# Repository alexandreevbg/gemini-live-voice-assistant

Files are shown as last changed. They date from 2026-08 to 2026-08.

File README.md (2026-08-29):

# Chochko: Multilingual Gemini Voice Assistant

A high-performance, private voice assistant, featuring multilingual wake word detection and Google Gemini Live integration.

## Project Overview
Project highlights:
- **Hardware:** Raspberry Pi + ReSpeaker 2-Mic v2.0
- **Platform:** Raspberry Pi OS Trixie (Debian 13) · Python 3.13 · aarch64
- **Advanced Audio Processing:** Utilizes PipeWire with Acoustic Echo Cancellation (AEC) for voice capture
- **On-Device Wake Word Detection:** Efficient and private wake word recognition based on MicroWakeWord models
- **Gemini Live Integration:** Seamless conversational AI powered by Google's **Gemini Live API**

Optional features:
- **Custom Wake Word:** Training a custom MicroWakeWord model, provided Bulgarian **"Чочко"** as an example
- **Home Assistant:** Optional integration for smart device control
- **Spotify:** for music streaming from Spotify or Home Assistant Media Player

More technical details:
- **Linux Kernel:** 6.18.39+rpt-rpi-v8 · aarch64
- **Python version:** 3.13.5
- **pymicro-wakeword:** bundles its own TFLite C library — no ai-edge-litert/tflite-runtime needed

## Repository structure
Besides a specific instruction file in each folder, you can find the related resources in:
- **01-platform** - Makefile to compile and setup ReSpeaker drivers and ReSpeaker schematic diagram
- **02-tools** - Python scripts for headless WiFi captive portal
- **03-environment** - Template for definition of environment variables and music clip for test AEC
- **04-wakeword** - Install/test MicroWakeWord, obtain or train a wake word model (pretrained, Colab, or local)
- **05-voice_assist** - The voice assistant package in Python
- **06-enclosure** - 3D printing files (STL), exploded component view, and hardware wiring diagrams

## Implementation Roadmap

Follow these steps to build your voice assistant:

----
### 1. [Platform Setup](./01-platform/platform.md)
Hardware specifications, flashing Raspberry Pi OS (Trixie), and compiling ReSpeaker 2-mic v2.0 drivers.

### 2. [Python and Tools](./02-tools/tools.md)
Create a common Python environment, and install the system backup tool, headless Wi-Fi captive portal, and Raspotify integration.

### 3. [Environment & Audio Stack](./03-environment/environment.md)
Install, setup, and test PipeWire with AEC (Acoustic Echo Cancellation).

### 4. [Wake Word & Training](./04-wakeword/wakeword.md)
Install and test the microWakeWord library. Obtain a keyword model, or create one via a pretrained model, Colab notebook (English), or local training (any language supported by Google and/or Edge TTS).

### 5. [Voice Assistant Core](./05-voice_assist/voice_assist.md)
Install, setup and test the main Python package, Gemini API integration, and optional Home Assistant and Spotify integrations.

### 6. [Enclosure & Assembly](./06-enclosure/enclosure.md)
An enclosure for the voice assistant in the form of 3D printing files (STL), exploded component view, and a wiring diagram.

---
---
---
## 📜 License
This project is licensed under the MIT License - see the [LICENSE](https://opensource.org/license/mit) file for details.

---

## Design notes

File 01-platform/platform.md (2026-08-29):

# Platform: Hardware, OS, and Drivers

This guide covers the base layer of the assistant, including hardware specifications, OS installation, and driver setup for the ReSpeaker 2-mic HAT v2.0.

----

## Hardware Requirements
| Component | Specification |
|---|---|
| **SBC** | Raspberry Pi Zero 2W |
| **Audio** | Seeed Studio ReSpeaker 2-Mic HAT v2.0 |
| **SD Card** | 16GB+ Class 10 |

## 1. Install Raspberry Pi OS (64-bit) Lite

Use **Raspberry Pi Imager** to flash your SD card:
- **Device:** Raspberry Pi Zero 2W
- **OS:** Raspberry Pi OS Lite (64-bit). This project is tested on **Debian 13 (Trixie)** / Testing branch for Python 3.13 support.
- **Settings:** Enable SSH, set your username (e.g., `chochko`), and configure your Wi-Fi credentials.

### Preliminary System Configuration
Optimize the system for headless use and speed up SSH login:

   ```bash
   # Enable passwordless sudo for the current user
   echo "$USER ALL=(ALL) NOPASSWD: ALL" | sudo tee /etc/sudoers.d/010_nopasswd

   # If login takes too much time, then disable motd scripts
   sudo chmod -x /etc/update-motd.d/*
   ```

Disable onboard audio and Bluetooth to prevent conflicts and save resources:
   ```bash
   sudo nano /boot/firmware/config.txt
   ```
   Change the following lines:
   ```bash
   dtparam=audio=off
   dtoverlay=vc4-kms-v3d,noaudio # Ensure this line is present and uncommented
   ```
   And add the following line to the end of the file:
   ```bash
   dtoverlay=disable-bt             # disable bluetooth if not used
   ```

Monitor CPU Temperature
   ```bash
   watch 'vcgencmd measure_temp'
  ```   

## 2. Install Drivers for ReSpeaker 2-mic HAT

Since newer kernels require manual building of the TLV320AIC3104 codec driver:

#### Build the Driver
   ```bash
   ## Install kernel
   sudo apt update
   sudo apt install flex bison libssl-dev bc build-essential libncurses-dev git device-tree-compiler -y
   git clone --depth=1 --branch rpi-6.12.y https://github.com/raspberrypi/linux.git

   ## Copy code and a Makefile
   mkdir ~/tlv320aic3x_i2c_driver
   cd ~/tlv320aic3x_i2c_driver
   cp ~/linux/sound/soc/codecs/tlv320aic3x.c .
   cp ~/linux/sound/soc/codecs/tlv320aic3x.h .
   cp ~/linux/sound/soc/codecs/tlv320aic3x-i2c.c .

   # Use the Makefile provided in the 01-platform directory of this repo
   wget https://raw.githubusercontent.com/alexandreevbg/gemini-live-voice-assistant/main/01-platform/Makefile

   ## Build the driver 
   make
   sudo make install
   sudo modprobe snd-soc-tlv320aic3x-i2c
   ```

#### Install the Overlay
   ```bash
   curl -L https://raw.githubusercontent.com/Seeed-Studio/seeed-linux-dtoverlays/master/overlays/rpi/respeaker-2mic-v2_0-overlay.dts -o respeaker-2mic-v2_0-overlay.dts
   dtc -I dts respeaker-2mic-v2_0-overlay.dts -o respeaker-2mic-v2_0-overlay.dtbo
   sudo cp respeaker-2mic-v2_0-overlay.dtbo /boot/firmware/overlays/
   ```

Add the overlay to `config.txt`:
   ```bash
echo "dtoverlay=respeaker-2mic-v2_0-overlay" | sudo tee -a /boot/firmware/config.txt
sudo reboot
   ```

## 3. Audio Testing & ALSA Calibration

Check if the card is detected:
   ```bash
   aplay -l
   arecord -l
   ```
It should appear as `card 0: seeed2micvoicec`.

### Set Gains via Alsamixer
   Run `alsamixer` and configure the following important sliders:
   - **PCM**: Master output volume - set to 100%
   - **Line DAC**: Max output voulme limit - set to 66
   - **PGA / Capture**: microphone Analog Gain - set to ~34%
   - **AGC**: Automatic Gain Control - recommended to turn it **OFF**

Save levels with:
   ```bash
   sudo alsactl store
   ```   

Test recording:
   ```bash
   arecord -r 16000 -c 1 -f S16_LE -t wav -d 5 test.wav
   aplay test.wav
   ```

Cleanup source fles:
   ```bash
   cd ~ 
   rm -rf ~/linux
   ```

---
[Return to Main README](../README.md)

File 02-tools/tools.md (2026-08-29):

# Tools: Python Environment, WiFi Captive Portal, Backup, Raspotify

This part guides through the setup of the Python virtual environment and installation of three optional, but recommended tools:
1. System backup tool - a fast and efficient backup tool for IoT project
2. Headless Wi-Fi captive portal - if you plan to travel with your device
3. Raspotify - Spotify Connect client for Raspberry Pi - if you plan to play music on your device  

You can install the optional tools later.

---

## 1. Python Virtual Environment
We use a shared virtual environment (`~/.venv`) to manage Python dependencies efficiently and consistently across different project components.

```bash
sudo apt update
sudo apt install -y python3-venv python3-pip
python3 -m venv --system-site-packages ~/.venv
```

Download the project locally
```bash
cd ~
git clone https://github.com/alexandreevbg/gemini-live-voice-assistant.git
```

## 2. Install the optional tools

### 1. System backup tool
For a backup solution, use **RonR-RPi-image-utils**, which quickly and efficiently creates a complete backup of a Raspberry Pi in the form of an image file.

Install NFS and the backup application
   ```bash
   sudo apt update
   sudo apt install nfs-common git -y
   git clone https://github.com/seamusdemora/RonR-RPi-image-utils
   sudo install --mode=755 ./RonR-RPi-image-utils/image-* /usr/local/sbin
   ```
Mount an external drive to store the image and run backup
   ```bash
   sudo mount -t nfs -o proto=tcp,port=2049 <NAS IP address>/<target directory> /mnt
   sudo image-backup -o -v
   ```
   After running the command, enter the name of the target image to /mnt/image_name.img, then answer with [OK] and 'y' to the subsequent questions. The resulting image is typically less than or about 4 GB. You may compress it using 7-Zip to a *.img.xz file with a size of less than 1 GB. Then, you can flash the image by Raspberry Pi Imager from the resulting or compressed image. 

---

### 2. Headless Wi-Fi captive portal
#### Reading the lights
| Light | What it means | What to do |
|---|---|---|
| 💙 **Blue flash** (once) | Starting up | Nothing — just booting |
| ❤️ **Red blinking** | Can't reach the internet | Wait, or press the button to set up Wi-Fi |
| 💙 **Blue pulsing** | Setup mode is on | Connect your phone (see below) |
| ⚫ **Off** | Connected and working | Nothing — you're good |

After power-on, the device flashes blue once, then tries to connect to a previously used Wi-Fi network. If it gets online, the light stays off and the device is ready. 
If it can't connect, the device blinks red 10 times, then tries again. This cycle repeats until a connection is established — or until you press the button to open the captive portal.
- **SSID**: Chochko-WiFi-Setup
- **Password**: chochko123
- **Portal address**: 192.168.4.1

Connect with your phone or computer, select a network from the list, enter the password, and press Connect. The device tries to connect and then reboots (whether or not it succeeded — if it failed, you'll see red blinking again and can retry).

If you don't finish within 300 seconds, the portal closes and the device returns to red blinking. Press the button to reopen the portal, or disconnect the power to reboot.

You can also open the captive portal at any time by pressing and holding the button during boot until the light starts pulsing blue.

1. Install the LED driver library into the shared environment:
   ```bash
   ~/.venv/bin/pip install --upgrade pip setuptools
   ~/.venv/bin/pip install apa102-pi
   ```
2. Enable SPI interface in the Raspberry Pi configuration:
   ```bash
   sudo raspi-config
   ```
   Select "Interfacing Options" -> "SPI" -> "Yes".
3. Get the source scripts
   ```bash
   mv gemini-live-voice-assistant/02-tools/wifi-portal ~/wifi-config
   ```
4. Test the Wi-Fi configuration manually
   ```bash
   sudo ~/.venv/bin/python ~/wifi-config/wifi_portal.py
   ```
   When run, the device should blink once with blue light
5. Create a one-shot service for the portal
   ```bash
   sudo nano /etc/systemd/system/wifi-config.service
   ```
   Add the following content to the file. This service runs as `root` after the network comes online, executing the portal script from the correct directory and using the Python virtual environment.
   > **Note**: Replace `chochko` with your actual username if it's different.
   ```ini
   [Unit]
   Description=Wi-Fi Configuration Portal
   Wants=network-online.target
   After=network-online.target

   [Service]
   Type=oneshot
   User=root
   WorkingDirectory=/home/chochko/wifi-config
   ExecStart=/home/chochko/.venv/bin/python /home/chochko/wifi-config/wifi_portal.py

   [Install]
   WantedBy=multi-user.target
   ```
   Then, enable the service to run on boot:
   ```bash
   sudo systemctl enable wifi-config.service
   sudo reboot
   ```
You can change the captive portal parameters as SSID name/password and/or the portal address in the file `wifi-config/wifi_portal.py`.   

---

### 3. Raspotify - Spotify Connect client
To integrate with Spotify, we need to install **raspotify**. It creates a network player compatible with Spotify and Home Assistant.

1. install raspotify:

   ```bash
   sudo apt update
   curl -sL https://dtcooper.github.io/raspotify/install.sh | sh
   sudo systemctl status raspotify
   ```

2. Test the installation:
Run Spotify on your phone connected to the same WiFi SSID. Play some music, open devices menu, and select raspotify(chochko).

> **If you plan to also install PipeWire+AEC** (`03-environment.md`), raspotify's packaged system service will stop working once PipeWire takes ownership of the audio hardware (`snd_pcm_open ... Host is down`) — this happens regardless of which you install first. See `03-environment.md`'s "Raspotify vs PipeWire" section for the one-time fix (swapping to a user-level service). If you're not using PipeWire/AEC, no further action is needed here.

---
[Return to Main README](../README.md)

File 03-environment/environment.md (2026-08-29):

# Environment & Audio Stack
This section details the setup of the PipeWire audio server with Acoustic Echo Cancellation (AEC), an output limiter/compressor that keeps playback clean for the echo canceller, and essential configuration files.

## 1. Install PipeWire + AEC
PipeWire is used to manage audio streams and enable Acoustic Echo Cancellation (AEC), allowing the microphone to effectively filter out audio being played by the speaker.

Install PipeWire and its related components.
```bash
sudo apt install -y \
    pipewire \
    pipewire-alsa \
    pipewire-audio \
    wireplumber \
    libspa-0.2-modules
```    
Validate installation
```bash
pipewire --version
```
The expected version is 1.4.2 or newer.

## 2. Set AEC config
Create the necessary configuration directories and files for PipeWire and WirePlumber.
```bash
mkdir -p ~/.config/pipewire/pipewire.conf.d ~/.config/wireplumber/wireplumber.conf.d
```

Set Clock Configuration
```bash
nano ~/.config/pipewire/pipewire.conf.d/10-clock.conf
```
Copy/paste the following text into the file:
```text
context.properties = {
    default.clock.rate = 48000
    default.clock.allowed-rates = [ 48000 ]
    default.clock.quantum = 480
    default.clock.min-quantum = 480
    default.clock.max-quantum = 480
}
```

Set Echo Cancellation Configuration
```bash
nano ~/.config/pipewire/pipewire.conf.d/90-echo-cancel.conf
```
Copy/paste the following text into the file:
```text
context.modules = [
  {
    name = libpipewire-module-echo-cancel
    args = {
      library.name = "aec/libspa-aec-webrtc"

      # The AEC engine now runs in MONO
      audio.rate = 48000
      audio.channels = 1
      audio.position = [ MONO ]

      webrtc.high_pass_filter = true
      webrtc.noise_suppression = true       # rejects ambient room noise (helps the wake-word detector)
      webrtc.voice_detection = false
      # AGC off: it pumped the gain and dropped quiet syllables. Keep capture level fixed instead.
      webrtc.gain_control = false
      webrtc.experimental_agc = false
      webrtc.limiter = true
      webrtc.extended_filter = true         # models the longer echo tail
      # delay_agnostic off: speaker+mic share a fixed-latency board, so constant delay
      # re-estimation only caused spectral "wobble". A fixed path converges far cleaner.
      webrtc.delay_agnostic = false
      webrtc.experimental_ns = false        # second NS stage gated quiet speech
      webrtc.transient_suppression = false  # was clipping word onsets

      capture.props = {
        node.name = "aec_capture"
        # This MUST match the real ALSA node name from `wpctl status` / `pw-link -lo`.
        # On this hardware the active profile names it "stereo-fallback" (not "analog-stereo").
        target.object = "alsa_input.platform-soc_sound.stereo-fallback"
        
        # Hardware stays Stereo to keep driver happy
        audio.channels = 2
        audio.position = [ FL FR ]
        node.force-rate = 48000
        node.force-quantum = 480
      }
      source.props = {
        node.name = "aec_input"
        node.description = "Echo-Cancelled Mono Mic"
        media.class = "Audio/Source"
        audio.channels = 1
        audio.position = [ MONO ]
        priority.driver = 1500
        priority.session = 1500      
	  }
      sink.props = {
        node.name = "aec_output"
        node.description = "Echo-Cancel Mono Reference"
        media.class = "Audio/Sink"
        audio.channels = 1
        audio.position = [ MONO ]
        priority.driver = 1500
        priority.session = 1500      
	  }
      playback.props = {
        node.name = "aec_playback"
        # MUST match the real ALSA node name (see note in capture.props above).
        target.object = "alsa_output.platform-soc_sound.stereo-fallback"
        # Playback remains Mono (PipeWire will mix it to the single speaker)
        audio.channels = 1
        audio.position = [ MONO ]
        node.force-rate = 48000
        node.force-quantum = 480
      }
    }
  }
]
```

Force Quantum Rate for ALSA
```bash
nano ~/.config/wireplumber/wireplumber.conf.d/50-force-480.conf
```
Copy/paste the following text into the file:
```text
monitor.alsa.rules = [
  {
    matches = [ { node.name = "~alsa_input.*" } ]
    actions = { update-props = { node.force-quantum = 480 } }
  },
  {
    matches = [ { node.name = "~alsa_output.*" } ]
    actions = { update-props = { node.force-quantum = 480 } }
  }
]
```

## 3. Output Limiter / Compressor
The WebRTC `limiter` enabled above only acts on the **capture** (microphone) signal — it does **not** touch the audio sent to the speaker. The ReSpeaker amplifier outputs ~1 W into a 3 W speaker, so the speaker itself is never at risk. The real problem is **distortion**: because section 7 forces the PCM slider to 100%, a loud TTS response or music spike can clip the amplifier. When that happens, the acoustic output is no longer a linear copy of the playback signal — and the WebRTC echo canceller assumes the echo *is* a linear function of its reference. Clipping breaks that assumption, so cancellation degrades and echo leaks into the mic. An independent `filter-chain` limiter/compressor on the **output** path keeps the signal below the clipping point, so the amp stays linear and AEC can do its job (it also evens out loudness so the assistant's voice stays consistent).

It is placed **before** the AEC sink (`apps → limiter_sink → aec_output → AEC → speaker`) so the echo reference is exactly the (already-limited) signal that reaches the speaker — preserving the linear relationship AEC depends on, since nothing after this point adds gain.

Install the LADSPA plugin set (provides the mono SC4 compressor/limiter):
```bash
sudo apt install -y swh-plugins
```
Confirm the plugin file is present (the control-port names used below are the standard swh-plugins names):
```bash
ls -l /usr/lib/ladspa/sc4m_1916.so
```
> **Note**: On 64-bit systems the plugin may instead live under an arch-specific path. If the command above fails, check `/usr/lib/aarch64-linux-gnu/ladspa/` and set `LADSPA_PATH` accordingly so PipeWire can find it.

```bash
nano ~/.config/pipewire/pipewire.conf.d/95-limiter.conf
```
Copy/paste the following text into the file:
```text
context.modules = [
  {
    name = libpipewire-module-filter-chain
    args = {
      node.description = "Speaker Limiter"
      media.name       = "Speaker Limiter"

      filter.graph = {
        nodes = [
          {
            type   = ladspa
            name   = comp
            plugin = sc4m_1916
            label  = sc4m
            control = {
              # 0 = RMS (smoother), 1 = peak (faster/harder)
              "RMS/peak"          = 0.0
              "Attack time (ms)"  = 10.0
              "Release time (ms)" = 150.0
              # Lower threshold + higher ratio = more limiting.
              "Threshold level (dB)" = -12.0
              "Ratio (1:n)"          = 6.0
              "Knee radius (dB)"     = 3.0
              # Keep makeup low so peaks stay below clipping; raise it for louder output.
              "Makeup gain (dB)"     = 2.0
            }
          }
        ]
      }

      # Virtual sink that apps play into (make this your default output)
      capture.props = {
        node.name        = "limiter_sink"
        node.description = "Limiter Output (Clean Playback for AEC)"
        media.class      = "Audio/Sink"
        audio.channels   = 1
        audio.position   = [ MONO ]
      }
      # Forward the limited signal into the AEC sink
      playback.props = {
        node.name      = "limiter_playback"
        target.object  = "aec_output"
        audio.channels = 1
        audio.position = [ MONO ]
      }
    }
  }
]
```
**Tuning:** For hard **clip protection** (brick-wall behaviour, keeps the amp out of distortion) set `"Ratio (1:n)" = 20.0`, `"Threshold level (dB)" = -6.0`, and `"Makeup gain (dB)" = 0.0`. For **loudness consistency** (voice assistant), use a lower ratio (3–6) with a few dB of makeup gain as above.

 Reboot
```bash
sudo reboot
```

**⚠ Verify the routing after restart.** With both this filter and the AEC active, the graph must form the chain `limiter_sink → aec_output → aec_playback → hardware`. Confirm the links — *not* just that nodes exist:
```bash
pw-link -lo
```
You must see exactly these connections:
```text
limiter_playback:output_MONO   ->   # limiter feeds the AEC reference
  |->aec_output:playback_MONO                    
aec_playback:output_FL              # AEC feeds the speaker
  |-> alsa_output.platform-soc_sound.stereo-fallback:playback_FL
aec_playback:output_FR
  |-> alsa_output.platform-soc_sound.stereo-fallback:playback_FR
```
If instead `aec_playback` connects to `limiter_sink`, or `limiter_playback` connects to the hardware, the chain is inverted — the AEC reference is silent and echo will **not** be cancelled. That happens when `aec_playback`'s `target.object` does not match the real hardware node name (see section 2). Both `target.object` values must resolve, otherwise WirePlumber falls back to default-sink routing and creates this inversion (or even a feedback loop).

## 4. Wipe the cached state and start fresh

Wipe any cached PipeWire state and restart the services to apply the new configuration.
```bash
systemctl --user stop pipewire wireplumber pipewire-pulse
rm -rf ~/.local/state/pipewire/*
systemctl --user start pipewire wireplumber pipewire-pulse
```

## 5. Force the metadata (Optional, but recommended)
```bash
pw-metadata -n settings 0 clock.force-rate 48000
pw-metadata -n settings 0 clock.force-quantum 480
```

## 6. Check and set the default audio nodes
Identify the IDs for `aec_input` and `limiter_sink` and set them as default.
```bash
wpctl status
```
Expected results like
```text
# ├─ Filters:
# │    - echo-cancel-1962-30
# │      39. aec_capture          [Stream/Input/Audio]
# │  *   40. aec_input            [Audio/Source]
 #│      41. aec_output           [Audio/Sink]
 #│      42. aec_playback         [Stream/Output/Audio]
 #│    - filter-chain-1962-31
 #│  *   43. limiter_sink         [Audio/Sink]
 #│      44. limiter_playback     [Stream/Output/Audio]
```

If the '*' are missing or on different lines, then manually set the default nodes (replace 40 and 43 with actual IDs):
```bash 
wpctl set-default 40	# aec_input
wpctl set-default 43	# limiter_sink
```
Reboot the system to ensure all changes are applied correctly.
```bash
sudo reboot
```

Verify pipewire is working as expected
```bash
systemctl --user status pipewire wireplumber pipewire-pulse
```

And check the default audio devices again
```bash
wpctl status # Look for aec_input and aec_output IDs
```
## 7. Force PCM slider to max volume
When start, PipeWire often set the PCM volume to 35% (80, 80). The simplest way to make it 100% is to run a single shoot service. For this:
1. Create new service file in the local systemd user directory:
```bash
mkdir -p ~/.config/systemd/user/
nano ~/.config/systemd/user/fix-pcm.service
```  

2. Paste the following configuration:
```text
[Unit]
Description=Force ReSpeaker PCM Volume to 100% after PipeWire starts
After=pipewire.service wireplumber.service

[Service]
Type=oneshot
ExecStartPre=/bin/sleep 3
ExecStart=/usr/bin/amixer -c 0 sset PCM 100%
RemainAfterExit=yes

[Install]
WantedBy=default.target
```

3. Save it and enable the service
```bash
systemctl --user daemon-reload
systemctl --user enable fix-pcm.service
```

4. reboot
```bash
sudo reboot
```

## 8. Test AEC
Play music and record speech at the same time for 10 sec
```bash
pw-play gemini-live-voice-assistant/03-environment/music_48k.wav &
pw-record test.wav &
sleep 10
killall pw-play pw-record
sleep 2
pw-play test.wav
```
Run alsaamixer in terminal 2, select card 0 "seeed2mic..." and find the max volume of Line DAC slider, while when the above test is working well.

## 9. Raspotify vs PipeWire (if you installed Raspotify)

If you installed Raspotify (`02-tools.md`'s optional step 3) — whether before or after this section — its packaged **system**-level service tries to open ALSA directly, which conflicts with PipeWire now owning the audio hardware: it crash-loops with `snd_pcm_open ... Host is down (112)`. This happens regardless of install order — it's a standing runtime conflict between two things wanting exclusive ALSA access, not something a particular install sequence avoids.

The fix: mask the system service, then run `librespot` as a **user**-level service instead — it shares your PipeWire session via `pipewire-pulse`, so audio routes through the same limiter/AEC chain set up above.

```bash
sudo systemctl disable --now raspotify
sudo systemctl mask raspotify
systemctl is-active raspotify        # expect: inactive

which librespot                      # expect /usr/bin/librespot
```

Create the user service:
```bash
mkdir -p ~/.config/systemd/user
nano ~/.config/systemd/user/raspotify.service
```
Paste the following, replace `YOUR_USERNAME` with your login (e.g. `chochko`). If `which librespot` returned a different path, fix the `ExecStart` line to match:
```text
[Unit]
Description=Raspotify (Spotify Connect)
After=pipewire.service wireplumber.service pipewire-pulse.service
Wants=pipewire.service pipewire-pulse.service

[Service]
ExecStartPre=/bin/sleep 5
ExecStart=/usr/bin/librespot \
    --name "Chochko" \
    --bitrate 320 \
    --format S32 \
    --backend pulseaudio \
    --device default \
    --device-type speaker \
    --initial-volume 100 \
    --systemctl --user daemon-reload
    --systemctl --user restart raspotify
    --cache "/home/YOUR_USERNAME/.cache/raspotify"
Restart=on-failure
RestartSec=10

[Install]
WantedBy=default.target
```
Start the service:
```bash
systemctl --user daemon-reload
systemctl --user enable --now raspotify
sleep 8
systemctl --user status raspotify | grep Active
```

Then **log the device in once**: open Spotify on your phone, tap the devices icon, select **Chochko**, and play something. librespot authenticates over zeroconf (the same way your phone already discovers it) and caches the session in `--cache`, so it reconnects automatically on every boot afterwards.

> No credential script is needed. An earlier version of this guide piped a remote `…/run.sh | sh` to pre-seed `credentials.json`. That is both unnecessary (zeroconf + `--cache` already persists the login) and risky — it runs unreviewed remote code as your user. Skip it.

**Troubleshooting — visible on phone but won't play (`snd_pcm_open ... Host is down`):** the system package is still active. Confirm and fix:
```bash
systemctl is-active raspotify          # system service — should be inactive/masked
sudo systemctl disable --now raspotify
sudo systemctl mask raspotify
systemctl --user restart raspotify
journalctl --user -u raspotify -n 20 --no-pager
```

**Next**: to let the voice assistant control playback by voice (play/pause/volume/search), continue to `05-voice_assist/voice_assist.md` §3.1 for Web API authorization.

---
[Return to Main README](../README.md)

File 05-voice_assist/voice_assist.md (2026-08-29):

# Voice Assistant: Installation & Testing Guide

This guide covers installation of the voice assistant and integrations with Home Assistant and Spotify.

## 1. Set API keys for integrations
Move the .env template from the repository to your home directory and open it to populate with your actual credentials.
```bash
cp ~/gemini-live-voice-assistant/03-environment/.env ~
chmod 600 ~/.env
nano .env
```
You should obtain at least a GEMINI API key and OPENWEATHER API key. Other integrations are optional.

### To Obtain YOUR_GEMINI_API_KEY
Visit [Google AI Studio](https://aistudio.google.com/), sign in, and click **"Get API key"** to generate your credential. Copy the key and paste it into the placeholder in the .env file.

### To Obtain YOUR_OPENWEATHER_API_KEY
Sign up at [OpenWeatherMap](https://openweathermap.org/api), select the tab **API Keys** and generate a new key by the button "Generate". Copy the key and paste it into the .env file.

### To Obtain YOUR_HOME_ASSISTANT_TOKEN
In your Home Assistant UI, click your **User Profile** (bottom-left icon) → scroll to the bottom → **"Long-Lived Access Tokens"** → **"Create Token"**. Copy the token and paste it into the .env file.

### To Obtain YOUR_SPOTIFY_CLIENT_ID and YOUR_SPOTIFY_CLIENT_SECRET
Login or Signin to [Spotify Developer Dashboard](https://developer.spotify.com/dashboard) → Home → Dashboard → Create App. Ensure you set the **Redirect URI** to `http://127.0.0.1:8888/callback. After app is created, copy the Client ID and Client Secret and paste them into the .env file.

You should replace at least YOUR_GEMINI_API_KEY and YOUR_OPENWEATHER_API_KEY with real API_KEYs. Other variables are optional. While they are commented, the voice assistant will consider the related integrations as "not available". Once you obtain the Home Assistant and/or Spotify keys, you can uncomment the corresponding variables and populate them with your tokens and keys.

Add those two lines to your `~/.bashrc` file to automatically load your environment variables and activate your Python virtual environment when you start a new shell session.
```bash
echo 'set -a; source ~/.env; set +a' >> ~/.bashrc
echo 'source ~/.venv/bin/activate' >> ~/.bashrc
sudo reboot
``` 

## 2. Install Voice Assistant Package

1. Install System Dependencies
```bash
sudo apt update
sudo apt install -y python3-dev portaudio19-dev alsa-utils
```

2. Install Python Packages
```bash
pip install sounddevice numpy scipy websockets requests spotipy
```

3. Move Source Files to Home Directory
```bash
mv ~/gemini-live-voice-assistant/05-voice_assist/voice_assist ~/voice_assist
```

## 3. Setup Spotify Connect device (optional)

Playing music needs two things, and both require **Spotify Premium** (Connect / librespot does not work on free accounts):

- **A playback device** named `Chochko` on your network — provided by librespot / raspotify. Install raspotify in `02-tools.md`, then set up its **user-level service** in `03-environment.md`'s "Raspotify vs PipeWire" section — the packaged system service conflicts with PipeWire owning the audio hardware, so that step lives there now rather than here. Do that first if you haven't already.
- **Web API authorization** so the assistant can see that device and control it (play / pause / volume / transfer) — the step below.

### 3.1 Authorize the Web API (one-time)
Do this **after** raspotify's user-level service (set up in `environment.md`) is running — the verification at the end lists Spotify devices, which only shows **Chochko** if that service is up.

The app and credentials are already set up in Section 1 (redirect URI `http://127.0.0.1:8888/callback`, Client ID / Secret in `~/.env`). Mint the token cache that the assistant reads:
```bash
cd ~/voice_assist
python spotify_auth.py
```
1. Open the printed URL in a browser on your **phone or laptop** (the Pi has no browser).
2. Log in and approve. The browser then tries to load `http://127.0.0.1:8888/callback?code=…` and **fails to load — that is expected** (nothing listens on the Pi; only the `?code=…` in the address bar matters).
3. Copy the **entire** address-bar URL and paste it back at the prompt.

`spotify_auth.py` exchanges the code, writes `~/.spotify_cache`, then verifies that your account shows `premium` and that **Chochko** appears in your device list. After this the assistant uses the cached token automatically and refreshes it as needed.

> The account you authorize here must be the **same Premium account** raspotify is logged into — Connect only lists devices on your own account. Run this as the **same user** that runs the assistant, so the cache lands in the right home directory.

## 4. Test Individual Components
These checks verify each piece of hardware and each integration in isolation, so that if something fails later you already know which part is healthy. Run them on the Pi (most need the real hardware), one at a time, with the `.venv` active. Each test prints an `... OK` line on success — if you see a Python traceback or a `FAILED` message instead, fix that component before moving on.
```bash
cd ~/voice_assist
source ~/.venv/bin/activate
```

1. Test SPI / LEDs
```bash
python3 -c "
import spidev, time
spi = spidev.SpiDev()
spi.open(0, 0)
spi.max_speed_hz = 1000000
def write(r, g, b):
    buf = [0]*4
    for _ in range(3):
        buf += [0xFF, b, g, r]
    buf += [0xFF]*4
    spi.xfer2(buf)
write(0, 0, 80);  time.sleep(1)   # blue
write(80, 0, 80); time.sleep(1)   # magenta
write(80, 0, 0);  time.sleep(1)   # red
write(0, 0, 0)                    # off
spi.close()
print('LEDs OK')
"
```
> **Watch the 3 LEDs.** They should light **blue → magenta → red** (1 second each), then switch **off**, and print `LEDs OK`. If the colours look wrong (e.g. red/blue swapped) the byte order is off; if nothing lights, check the HAT seating and that SPI is enabled.

2. Test Microphone
```bash
python3 -c "
import sounddevice as sd, numpy as np
print('Devices:')
print(sd.query_devices())
print()

chunks = []
def cb(indata, frames, t, status):
    chunks.append(indata.copy())
    if len(chunks) == 1:
        print(f'dtype={indata.dtype} shape={indata.shape}')

with sd.InputStream(samplerate=48000, channels=2, dtype='int32',
                    blocksize=3840, callback=cb):
    sd.sleep(2000)
print(f'Received {len(chunks)} chunks - Mic OK')
"
```
> Prints the device list, then captures audio for ~2 seconds. You should see a non-zero chunk count and `Mic OK`. Confirm the ReSpeaker 2-Mic array appears in the device list; if `Received 0 chunks` or it errors, the mic isn't being picked up — recheck the PipeWire/ALSA setup and the HAT.

3. Test Playback / Speaker
```bash
python3 -c "
import sounddevice as sd, numpy as np
t    = np.linspace(0, 1, 48000, False)
tone = (np.sin(440 * 2 * np.pi * t) * 0.3 * 32767).astype(np.int16)
stereo = np.column_stack([tone, tone])
sd.play(stereo, samplerate=48000)
sd.wait()
print('Speaker OK')
"
```
> **Listen.** You should hear a clear 1-second 440 Hz tone (musical note A) from the speaker, then `Speaker OK`. No sound usually means the wrong output device or a muted/low volume — check the speaker connection and the PipeWire default sink.

4. Test Button
```bash
python3 -c "
from gpiozero import Button
import time
btn = Button(13, pull_up=False)
print('Touch the button (GPIO13)...')
btn.wait_for_press(timeout=10)
print('Button pressed - GPIO OK')
"
```
> When you see `Touch the button (GPIO13)...`, **touch the sensor** within 10 seconds. Success prints `Button pressed - GPIO OK`. If it exits after 10 s with no message, the touch wasn't registered — check the wiring/pin (GPIO13). This is a TTP223 touch sensor, active HIGH (`pull_up=False`) — not a mechanical switch, so no internal pull-up is used.

5. Test Wake Word Detection
To test wake word detection, run the following script:
```bash
cd ~/voice_assist
python3 -c "
import logging, time
logging.basicConfig(level=logging.INFO, format='%(name)s: %(message)s')
from capture import MicCapture
from wakeword import create_detector
import config

det = create_detector(config.WAKEWORD_MODEL)
mic = MicCapture(); mic.add_consumer(det.process); mic.start()

print('Say the wake word (10s)...')
start = time.time()
while time.time() - start < 10:
    time.sleep(0.05)
    if det._detected:              # set synchronously inside process()
        print('>>> WAKE WORD DETECTED <<<')
        break
mic.stop()
print('Detected' if det._detected else 'Not detected')
"
```
> After `Say your wake word now`, **speak your wake word** clearly within 10 seconds. Success prints `WAKE WORD DETECTED!`. If it reports `Wake word not detected in 10s`, try speaking louder/closer, or lower `probability_cutoff` in the model's JSON manifest (a lower cutoff is more sensitive but risks false triggers).

6. Test Gemini Connection
```bash
python3 -c "
import asyncio, os, sys
sys.path.insert(0, '.')
import config

async def test():
    import websockets, json
    url = (
        'wss://generativelanguage.googleapis.com/ws/'
        'google.ai.generativelanguage.v1beta.'
        f'GenerativeService.BidiGenerateContent?key={config.GEMINI_API_KEY}'
    )
    try:
        ws = await asyncio.wait_for(websockets.connect(url), timeout=10)
        setup = json.dumps({
            'setup': {
                'model': config.GEMINI_MODEL,
                'generation_config': {'response_modalities': ['AUDIO']}
            }
        })
        await ws.send(setup)
        msg = json.loads(await ws.recv())
        print('Gemini response:', list(msg.keys()))
        await ws.close()
        print('Gemini Live connection OK')
    except Exception as e:
        print(f'Gemini connection FAILED: {e}')

asyncio.run(test())
"
```
> Needs working internet and a valid `GEMINI_API_KEY` in your environment. Success prints the response keys and `Gemini Live connection OK`. A `Gemini connection FAILED:` message points at the cause — usually a bad/missing API key, no internet, or a wrong `GEMINI_MODEL` name in `config.py`.

7. Test Spotify
```bash
python3 -c "
import sys, os, time
sys.path.insert(0, '.')
from spotify import SpotifyController
import logging
logging.basicConfig(level=logging.INFO)

sp = SpotifyController()
ok = sp.connect()
print('Connected:', ok)
if ok:
    devices = sp._sp.devices()
    print('Devices:')
    for d in devices['devices']:
        print(f'  {d[\"name\"]} active={d[\"is_active\"]}')
    current = sp.get_current()
    print('Now playing:', current)
    print()
    print('Testing volume...')
    sp.set_volume(75)
    time.sleep(1)
    sp.set_volume(100)
    print('Spotify OK')
"
```
> Requires raspotify's user-level service (`environment.md`) and §3.1 above (Web API authorized) done. It lists your Spotify devices — **Chochko** should be among them — shows what's playing, and steps the volume 50 → 100 (if something is playing you'll hear it change). Success prints `Spotify OK`. `Connected: False` means the token cache is missing or the account isn't Premium — rerun `spotify_auth.py`.

8. Test Weather
```bash
python3 -c "
import sys
sys.path.insert(0, '.')
import weather, location

loc = location.get_current()
print('Location:', loc)
w = weather.get_weather(loc['town'], loc['country'])
print('Weather:', w)
print('Formatted:', weather.format_for_gemini(w))
"
```
> Resolves your location, then fetches the current weather for it. You should see a plausible town/country and a weather summary — no traceback. If the location looks wrong, check the Location test (#10); if the weather call fails, verify internet and any weather API settings.

9. Test Home Assistant
```bash
python test_ha.py
```

The interactive test script:
1. Lists all loaded entities and aliases
2. Tests entity search by name/alias
3. Shows device status
4. Interactive control prompt

> This one is **interactive** — it waits for your input. Confirm your Home Assistant entities and aliases appear in the list, then use the control prompt to toggle a device (e.g. a light) and check it actually responds. An empty entity list or connection error means the HA URL/token in your config is wrong or HA is unreachable. Press `Ctrl+C` to exit when done.

10. Test Location
```bash
python3 -c "
import sys
sys.path.insert(0, '.')
import location
loc = location.get_current()
print('Location:', loc)
print('Prompt string:', location.format_for_prompt(loc))
"
```
> Prints your detected location and the formatted string the assistant feeds to the model. Check the town/country are correct — this drives both the weather lookup (#8) and any location-aware answers. If it's wrong or empty, verify internet access and the location source (e.g. IP-based geolocation can be off; set an override in config if needed).

## 5. Run Voice Assistant From Command Line

Normal run
```bash
python main.py
```

Run with log saved to file
```bash
python main.py 2>&1 | tee ~/voiceAssist/session.log
```

Run with debug logging
In `config.py` set `DEBUG = True`, then:
```bash
python main.py 2>&1 | tee ~/voiceAssist/debug.log
```

Check for false wake word detections
```bash
grep "score" ~/voiceAssist/session.log
grep "Wake word" ~/voiceAssist/session.log
```

## 6. Systemd Autostart Services
1. Create voice assistant service
```bash
nano ~/.config/systemd/user/voiceassist.service
```
Copy/paste the following and change YOUR_USERNAME with your user (chochko):
```text
[Unit]
Description=Chochko Voice Assistant
After=pipewire.service wireplumber.service pipewire-pulse.service raspotify.service
Wants=pipewire.service pipewire-pulse.service raspotify.service

[Service]
WorkingDirectory=/home/YOUR_USERNAME/voice_assist
EnvironmentFile=/home/YOUR_USERNAME/.env
ExecStartPre=/bin/sleep 10
ExecStart=/home/YOUR_USERNAME/.venv/bin/python main.py
Restart=on-failure
RestartSec=10
StandardOutput=journal+console
StandardError=journal+console
SyslogIdentifier=voiceassist

[Install]
WantedBy=default.target
```
Run the service:
```bash
systemctl --user daemon-reload
systemctl --user enable voiceassist
```

2. Enable linger (start services at boot without login)
```bash
sudo loginctl enable-linger YOUR_USERNAME
loginctl show-user YOUR_USERNAME | grep Linger
# Expected: Linger=yes
```

3. Start and verify all services
```bash
systemctl --user start voiceassist
sleep 12

systemctl --user status pipewire wireplumber pipewire-pulse \
    raspotify voiceassist | grep -E "Active|Main PID"
```

All 5 should show `active (running)`.

4. View logs

```bash
# Follow live logs
journalctl --user -u voiceassist -f

# Last 50 lines
journalctl --user -u voiceassist -n 50

# Filter for errors only
journalctl --user -u voiceassist -n 100 | grep -E "ERROR|WARNING"
```

5. Quick Verification Checklist
```
Hardware:
[ ] SPI enabled (ls /dev/spidev*)
[ ] LEDs blink blue on test
[ ] Mic records audio (non-zero samples)
[ ] Speaker plays tone
[ ] Button detected on GPIO13

Software:
[ ] Wake word detected within 10s
[ ] Gemini WebSocket connects
[ ] Spotify device visible
[ ] Weather returns data
[ ] Home Assistant loads entities

Services (after reboot):
[ ] pipewire active
[ ] wireplumber active
[ ] pipewire-pulse active
[ ] raspotify active
[ ] voiceassist active
```

## Common Issues

### SPI permission denied
```bash
# Verify SPI enabled
ls /dev/spidev*
# If missing: sudo raspi-config nonint do_spi 0 && sudo reboot
```

### No audio devices found
```bash
systemctl --user status pipewire
systemctl --user restart pipewire wireplumber
```

### Spotify token expired
```bash
rm -f ~/.spotify_cache
python ~/voice_assist/spotify_auth.py
```

### Raspotify visible on phone but won't play (`snd_pcm_open ... Host is down`)
The **system** raspotify package is running and trying to open ALSA directly, which fails under PipeWire — see `03-environment.md`'s "Raspotify vs PipeWire" section for the full fix (mask the system service, run a user-level one instead). Quick check:
```bash
systemctl is-active raspotify                      # system service — should be inactive/masked
systemctl --user status raspotify | grep Active    # user service — should be active (running)
journalctl --user -u raspotify -n 20 --no-pager
```
If the user unit is missing (`Unit raspotify.service does not exist`), set it up per `environment.md` first.

### Home Assistant not connecting
```bash
# Test connectivity
curl -H "Authorization: Bearer $HA_TOKEN" \
     http://homeassistant.local:8123/api/ | python3 -m json.tool
```

### Wake word not detecting
```bash
# Check audio levels
alsamixer -c 0
# Adjust PGA level (target: speech clearly audible)
```

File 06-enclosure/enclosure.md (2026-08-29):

# Raspberry Pi Smart Speaker — Build Documentation

A spherical, full-duplex smart speaker built around a Raspberry Pi Zero 2W and a ReSpeaker 2-Mic HAT, with mechanical and acoustic design optimized for clean AEC (echo cancellation) at usable playback volumes.

## Design Goals

1. **Clean AEC at high volume** — the speaker should remain in its linear operating range across the useful volume range, so PipeWire's WebRTC AEC3 can maintain effective echo cancellation.
2. **Mic isolation from speaker vibration** — the microphones must hear room sound, not the enclosure's structural reaction to the driver.
3. **Adequate thermal dissipation** for the Pi SoC.
4. **Compact, aesthetically clean form** — spherical, with a clean visible parting line.
<br><br>

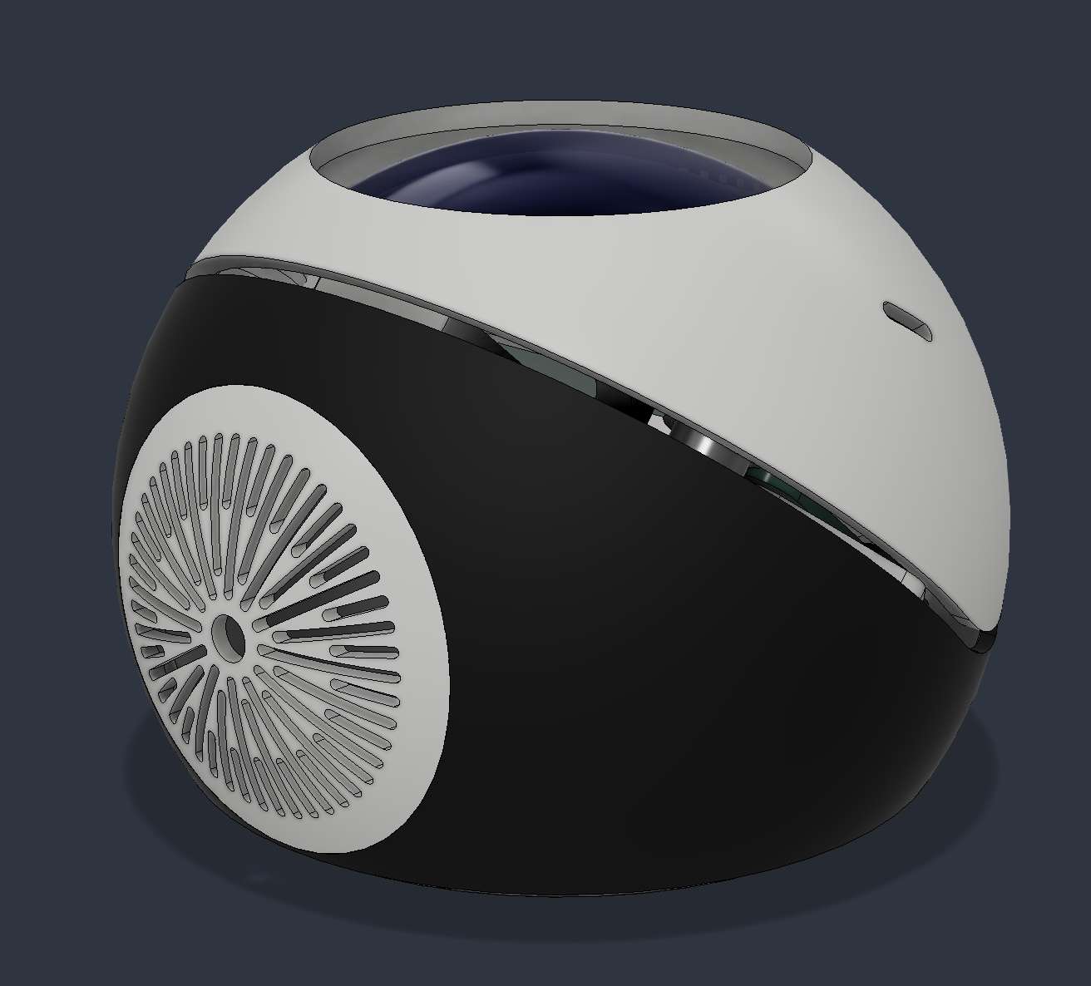
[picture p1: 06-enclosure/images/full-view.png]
Full view diagram


## Final Acoustic Architecture

| Decision | Choice | Rationale |
|---|---|---|
| Enclosure type | **Sealed or passive-radiator-loaded — selectable** | VA-Base's bottom washer hole accepts either insert: a **spile** (solid plug, no moving diaphragm) → plain sealed box; or a **passive radiator** (moving diaphragm, no motor) → passive-radiator-loaded box for reinforced bass without a second amplified driver. The steel washer seals/retains whichever insert is fitted. |
| Speaker mounting | Direct mount in VA-Base's front hole | Secured by **VA-Speaker grill**; sealed against the driver flange with **VA-O-ring** (TPU 95A). |
| PCB platform | Bent stainless-steel bracket, epoxied into VA-Base | A stainless steel disk with diameter 80 mm, cut into 2 parts (53.6 mm + 25.2 mm), bent at 40°, and glued with **VA-Stencil** as the jig; carries the M2.5-tapped mounts for the PCB legs and the cable slot.|
| Mic mounting | **VA-Mic tubes** (TPU 95A) sealed into VA-Middle | Acoustic tunnels between the ReSpeaker capsules and the outside. |
| Pi/HAT mounting | **VA-PCB holder** + **VA-PCB leg** (PLA top / TPU 95A bottom) | Legs bolt to the steel bracket through M2.5 threads; **VA-PCB leg gasket** (TPU 95A) sits between the leg's TPU foot and the bracket. |

## Exploded View
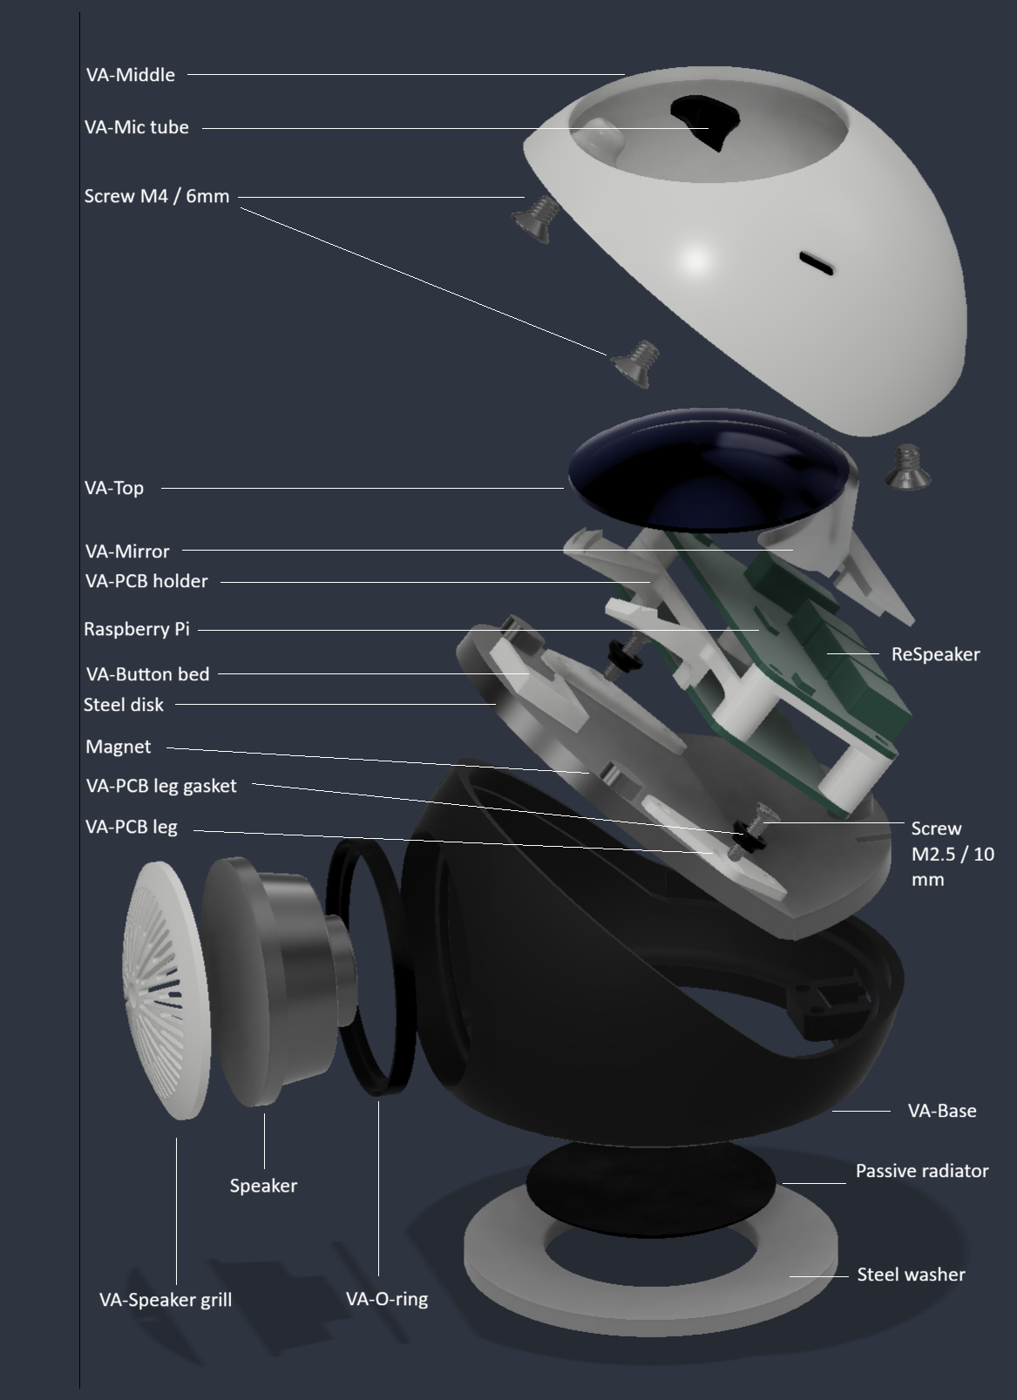
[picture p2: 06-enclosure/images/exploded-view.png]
Exploded view diagram


## 3D-Printed Parts

All spherical parts share an **82.8 mm outer diameter**.

| # | Part (STL) | Material | Print notes | Description |
|---|---|---|---|---|
| 1 | **VA-Base** | PLA | — | Speaker compartment, semi-sphere. Front: hole for a 40 mm 3 W speaker. Bottom: hole for either insert — a solid **spile** (sealed box) or a round low-frequency **passive radiator** ([source](https://www.aliexpress.com/item/1005003239721955.html)) — held/sealed in place by a standard steel washer, 60 mm OD × 34.8 mm ID × 3 mm thick ([source](https://www.aliexpress.com/item/1005006628614312.html)). Back: bed for a female micro-USB adapter ([source](https://www.aliexpress.com/item/32867946438.html)). |
| 2 | **VA-Middle** | PLA | — | RPi/ReSpeaker compartment, semi-sphere, same 82.8 mm diameter. 45 mm hole on top; two small side holes for the microphones. Also has three internal M4-threaded holes for countersink screws that stick to the magnets (see below). |
| 3 | **VA-Top** | PLA (semi-transparent) | Glued to VA-Mirror with super glue | Sits hollow-cheeked in VA-Middle's top hole; diffuses the ReSpeaker's status LEDs to the outside. |
| 4 | **VA-Speaker grill** | PLA | **0.2 mm nozzle** recommended for grille detail | Holds the speaker in place inside VA-Base. |
| 5 | **VA-Button bed** | PLA | Stuck to the steel bracket with double-sided adhesive tape | Mounting bed for the TTP223 touch sensor, positioned just under VA-Top, replacing the original mechanical button — see [Electrical Wiring](#electrical-wiring) below. |
| 6 | **VA-Mic tubes** | TPU 95A | Sealed into VA-Middle with super glue | Acoustic tunnels from the ReSpeaker mic capsules to VA-Middle's side holes. |
| 7 | **VA-Mirror** | PLA | Mirror surface painted with a mirror marker pen ([source](https://www.aliexpress.com/item/1005006677891105.html)); VA-Top glued to it with super glue | Redirects the ReSpeaker LEDs' light up into VA-Top; also mechanically supports VA-Top in position. |
| 8 | **VA-O-ring** | TPU 95A | — | Gasket between VA-Base and the speaker. |
| 9 | **VA-PCB holder** | PLA | — | Structure holding the RPi, ReSpeaker, and VA-Top. |
| 10 | **VA-PCB leg** | PLA (upper part) + TPU 95A (lower, concentric-circle part) | — | Fixes the PCB holder assembly to the steel bracket. |
| 11 | **VA-PCB leg gasket** | TPU 95A | — | Together with the leg's TPU foot, isolates the PCB structure from high-frequency vibration transmitted from the speaker compartment. |
| 12 | **VA-Stencil** | (jig, not part of final assembly) | — | Glue-up template for cutting/bending the steel bracket and for positioning the 3 magnets. |

## Steel Bracket (Purchased Stainless Disk, Cut + Bent)

Covers VA-Base's top opening, carrying the PCB assembly.

- Standard stainless steel disk, 3–4 mm thick ([source](https://www.aliexpress.com/item/1005011933984493.html)).
- Cut into two pieces: **53.6 mm** and **25.2 mm**.
- Bent to **40°**.
- Glued with **epoxy metal adhesive**, using **VA-Stencil** to hold the pieces in alignment while curing.
- Three holes per the stencil: two round, **M2.5**-tapped (left/right) to fix the PCB structure, and one slot beside the USB bed for the power and speaker cables to pass through.

## Magnets

- **3 × 8 mm diameter × 3 mm height.**
- Glued with super glue, or preferably **epoxy metal adhesive**.
- Positioned using the holes in **VA-Stencil**.

## Purchased Components

| Component | Spec | Source |
|---|---|---|
| Passive radiator (one of two bottom-hole insert options — see spile below) | sized to the washer's 34.8 mm ID aperture | [AliExpress](https://www.aliexpress.com/item/1005003239721955.html) |
| Spile (the other bottom-hole insert option) | solid plug, no moving diaphragm — makes VA-Base a plain sealed box instead | — |
| Steel washer | 60 mm OD × 34.8 mm ID × 3 mm thick — seals/retains whichever insert (spile or radiator) is fitted in VA-Base's bottom hole | [AliExpress](https://www.aliexpress.com/item/1005006628614312.html) |
| Female micro-USB adapter | — | [AliExpress](https://www.aliexpress.com/item/32867946438.html) |
| Stainless steel disk | 3–4 mm thick, standard | [AliExpress](https://www.aliexpress.com/item/1005011933984493.html) |
| Speaker | 40 mm, 3 W | — |
| Magnets | 8 mm ⌀ × 3 mm, ×3 | — |
| TTP223 touch sensor | GPIO13, active-HIGH — see [Electrical Wiring](#electrical-wiring) below | [AliExpress](https://www.aliexpress.com/item/1005005608987443.html) |
| Mirror marker pen | silvers VA-Mirror's reflective surface | [AliExpress](https://www.aliexpress.com/item/1005006677891105.html) |
| Heatsinks | 15 × 15 × 6.6 mm, ×2 (CPU + wireless module) | — |
| Thermal pad (optional, hot climates) | 2.3–2.5 mm thick, Pi board underside → steel bracket | — |
| External WiFi antenna (optional, if reception is weak) | see [WiFi Antenna](#wifi-antenna) below | — |
| Double-sided adhesive tape | sticks VA-Button bed to the steel bracket | — |
| Electrolytic capacitor | 100 µF / 6.3 V, soldered across Raspberry Pi power pins 4 and 6 for power smoothing | — |

## Electrical Wiring

1. **TTP223 touch sensor → ReSpeaker J4 connector:**
   - GND → pin 4
   - I/O → pin 2 (GPIO13)
   - VCC → pin 3

   The module is mounted just under VA-Top (VA-Button bed), instead of a mechanical button. VA-Button bed itself is stuck to the steel bracket with double-sided adhesive tape. A piece of wire is soldered to the module's touch pad and acts as an antenna, extending the touch-sensitive area up through VA-Top so the whole top surface responds to a touch rather than just the small board itself:

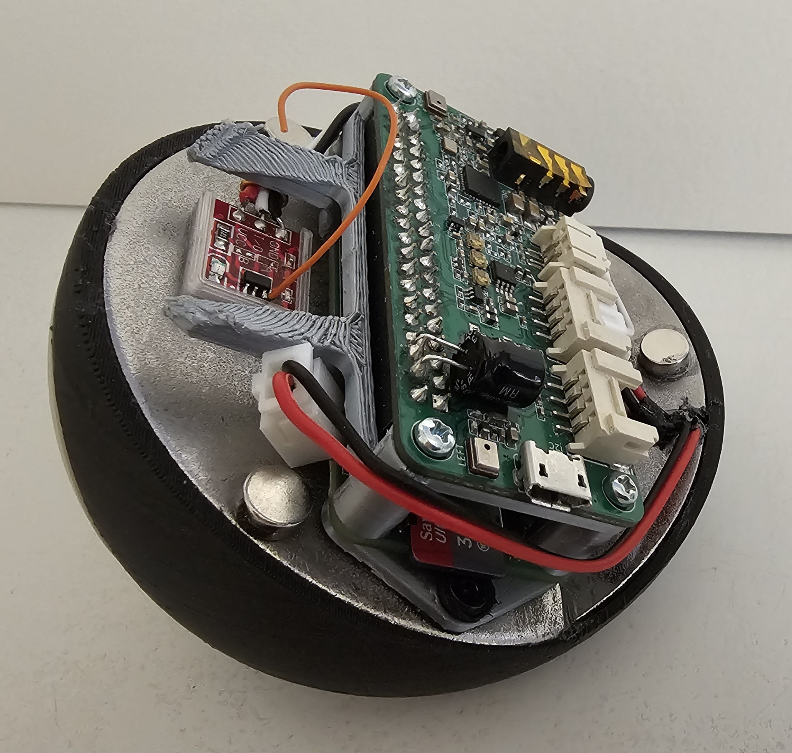
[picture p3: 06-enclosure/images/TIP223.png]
TTP223 touch sensor mounting
   

2. **Power (bypassing standard micro-USB):** a standard micro-USB port is too long to fit this construction. A male XH2.54 connector is soldered to Raspberry Pi pins 4 and 6, and the matching female XH2.54 is connected via a two-wire cable to the female USB-to-PAD adapter mounted in VA-Base's back bed. A **100 µF / 6.3 V electrolytic capacitor** is also soldered across pins 4 and 6, for power smoothing.

   The ReSpeaker HAT's own onboard button is not used and was removed.

3. **Speaker → ReSpeaker J2 connector:**
   - `−` → pin 2
   - `+` → pin 1
 
## WiFi Antenna

The Pi Zero 2W's onboard antenna sits close to the stainless steel bracket, which can attenuate WiFi reception. If you see connectivity trouble, add an external antenna as described in [this video](https://www.youtube.com/watch?v=IZqaKZLIqFg), and stick it to the bed on the back side of the VA-Mirror as shown here:

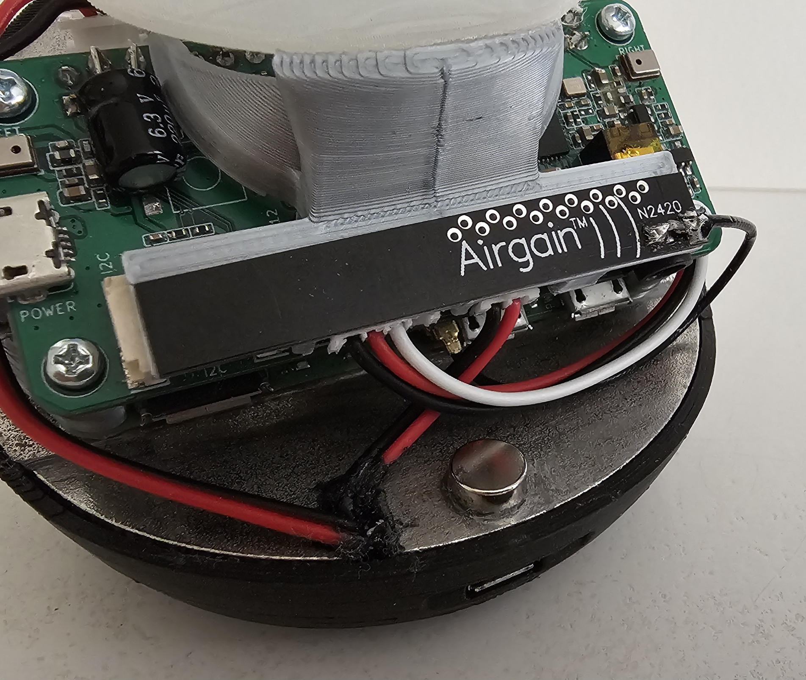
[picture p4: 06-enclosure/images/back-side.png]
External WiFi antenna placement


## Cooling

- A standard **15 × 15 × 6.6 mm heatsink** is fitted to each of the CPU and the wireless/communication module.
- The enclosure vents passively as a chimney: a **2 mm gap under VA-Middle** draws in cool air, and a **2+ mm gap between VA-Middle and VA-Top** exhausts warm air out the top.
- **In hot climates**, the stainless steel bracket can additionally serve as a heatsink for the whole Pi board — bond a **2.3–2.5 mm thick thermal pad** to the underside of the Pi board, against the bracket.

## Vibration Isolation

The speaker (in VA-Base) and the PCB assembly (RPi + ReSpeaker, in VA-PCB holder) are decoupled through two TPU 95A layers:

- **VA-O-ring** seals and decouples the speaker itself from VA-Base.
- **VA-PCB leg gasket**, together with the TPU (concentric-circle) foot of **VA-PCB leg**, isolates the PCB structure from high-frequency vibration transmitted through the steel bracket from the speaker compartment below.
- Don't fully tighten the **VA-PCB leg** screws into the steel bracket — leave them just loose enough that the whole PCB structure can wobble ever so slightly. Torquing them down solid re-introduces a hard, rigid contact path from the disk straight into the ReSpeaker microphones, defeating the gasket isolation above.

**VA-Mic tubes** (TPU 95A) carry mic pickup from the ReSpeaker capsules out through VA-Middle without a rigid path to the shell.

PipeWire/AEC/limiter setup and configuration live in [environment.md](../03-environment/environment.md) — see that doc for the echo-cancel module config, playback limiter, and routing verification.

## Testing & Validation

### Acoustic / Build Verification

1. **Pressure-leak test:** seal the speaker hole with your hand, press gently on VA-Base.
   - **With the spile fitted** (sealed box): pressure should release slowly. A quick release means a leak around the washer or USB bed.
   - **With the passive radiator fitted:** it's doing the compliance job now, so you should see *it* move/flex in response instead. If it doesn't move and pressure just leaks out around the washer or USB bed, that's a leak there.
2. **Tap test:** with everything assembled, tap VA-Base. The VA-PCB holder assembly above should feel *noticeably deader* than VA-Base — confirms the gasket isolation is working.
3. **Pink noise sweep:** `play -n -c 1 synth 30 pinknoise` (requires `sox`). Listen around the enclosure for buzzes, leaks, and rattles — pink noise reveals problems music masks.

### AEC Performance Verification

```bash
# Terminal 1 — play continuous tone through the full chain:
play -n synth 30 sine 1000

# Terminal 2 — record AEC output:
pw-record --target=aec_input aec_test.wav
# wait ~10 seconds, Ctrl+C, then:
pw-play aec_test.wav
```

The 1 kHz tone should be heavily attenuated in the recording. Repeat at progressively higher volumes; the level at which residual playback becomes audible defines your current AEC headroom.

### Thermal Verification

```bash
# Under sustained CPU load (e.g., audio processing):
watch -n 2 vcgencmd measure_temp
```

Pi Zero 2W should stabilize below ~70 °C under load. If it climbs higher, check thermal pad/paste contact pressure at the SoC, and whether the PCB holder gives the Pi enough clearance for passive convection.

## Vibration Bypass Paths — Pre-Build Checklist

The gasket-based isolation only works if the TPU layers are the **only** path from the speaker compartment to the PCB assembly. Verify before final assembly:

- [ ] **VA-O-ring** is correctly seated between the speaker and VA-Base — no metal-to-plastic contact bypassing it.
- [ ] **VA-PCB leg gasket** is seated flat between each leg's TPU foot and the steel bracket — no gaps, no crushed/rolled gasket.
- [ ] No metal-to-metal screw path exists between the steel bracket and the PCB holder that bypasses the TPU foot/gasket.
- [ ] Power/speaker cables through the bracket's cable slot are thin and have a service loop — not pulled taut.
- [ ] The steel bracket's epoxy bond (to VA-Base, via VA-Stencil alignment) has fully cured before load-testing.
- [ ] The bottom washer and USB bed are properly sealed — check for air leaks with the pressure test below.

## Materials Summary

| Material | Used for |
|---|---|
| PLA | VA-Base, VA-Middle, VA-Speaker grill, VA-Button bed, VA-Mirror, VA-PCB holder, VA-PCB leg (upper part) |
| PLA (semi-transparent) | VA-Top |
| TPU 95A | VA-Mic tubes, VA-O-ring, VA-PCB leg (lower, concentric-circle part), VA-PCB leg gasket |
| Stainless steel, 3–4 mm | Bracket cut from a purchased disk (53.6 mm + 25.2 mm pieces, bent 40°) |
| Epoxy metal adhesive | Steel bracket glue-up (via VA-Stencil), magnet mounting |
| Steel washer | Seals VA-Base's bottom hole, 60 mm OD × 34.8 mm ID × 3 mm |
| Magnets | 3 × 8 mm ⌀ × 3 mm |

## Design Notes To Expand

A few things worth documenting further once finalized — happy to add these when you have the details:

- Exact assembly order/sequence for the full stack.
- Cable routing detail from the bracket's slot through to the PCB.

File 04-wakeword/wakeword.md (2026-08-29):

# WakeWord: Install and Test microWakeWord. Obtain Wake Word Model.

## Install MicroWakeWord

### 1. System Dependencies
```bash
pip install -U pymicro-wakeword     # 2.3.0 or newer recommended
```

Version 2.3.0+ exposes `process_streaming_prob()`, which returns the raw
probability for logging/tuning. Versions 2.0–2.2 only expose
`process_streaming()` (returns a bool decision). The detector below works with
either; 2.3.0 just adds the live score logging.

`pymicro-wakeword` bundles its own `tensorflowlite_c` shared library and drives
it via ctypes, so **`ai_edge_litert`/`tflite_runtime` are not needed**.

### 2. Run Detection Script
Test the installed library with one of the builtin wakewords: alexa, hey_jarvis, hey_mycroft, or ok_nabu. To test with wake word Alexa, run the following command and say "Alexa":
```bash
arecord -D pipewire -r 16000 -c 1 -f S16_LE -t raw - | python3 gemini-live-voice-assistant/04-wakeword/microWW/test_mww.py --builtin alexa
```

To test with your own trained model instead, point `--config` at its JSON manifest:
```bash
arecord -D pipewire -r 16000 -c 1 -f S16_LE -t raw - | python3 gemini-live-voice-assistant/04-wakeword/microWW/test_mww.py --config gemini-live-voice-assistant/04-wakeword/microWW/chochko.json
```

`test_mww.py` reads post-AEC audio (PipeWire's default source). To compare
against the raw pre-AEC signal instead — useful for judging how much AEC is
actually helping — use the companion `test_mww_preaec.sh` script in the same
directory (see its header comment for usage; it taps the raw hardware
capture node directly via `pw-record`).

## Obtain MicroWakeWord Model
There are three options: use a pre-trained model, train your own in English via Colab, or train locally on your own PC (needed for non-English wake words like Bulgarian — the Colab-notebook route for that hit memory problems and was dropped in favor of local training).

### 1. Use a pre-trained model
Besides the built-in wake words, a collection of community pre-trained models is available in the following [repository](https://github.com/TaterTotterson/microWakeWords). The official ESPHome models live in the [micro-wake-word-models repo](https://github.com/esphome/micro-wake-word-models/tree/main/models/v2).

### 2. Train a custom wake word in English
The official training notebook is available on [GitHub](https://github.com/OHF-Voice/micro-wake-word/blob/november-update/notebooks/basic_training_notebook.ipynb).

> Training is **very** slow on CPU — set the Colab runtime to a **GPU** (Runtime → Change runtime type). Note that the install cell asks you to **restart the session** before continuing.

The notebook produces a quantized streaming model at
`trained_models/wakeword/tflite_stream_state_internal_quant/stream_state_internal_quant.tflite`.
To use it in ESPHome you must also write a small JSON model manifest — see the [ESPHome documentation](https://esphome.io/components/micro_wake_word) and the [model repo examples](https://github.com/esphome/micro-wake-word-models/tree/main/models/v2).

### 3. Train locally on your PC (WSL2 / Linux, CPU)

Google Colab's free tier now runs **Python 3.12** with only ~12 GB RAM, which causes
two problems for this notebook: a cascade of version-drift errors (the notebook
targets Python 3.10) and an out-of-memory kill partway through training. Training
**locally** sidesteps both — any PC with **≥16 GB RAM** finishes comfortably. No GPU
is required: the model is tiny, so CPU-only training takes on the order of an hour.

Ready-to-run scripts live in **04-wakeword/local/**. They reproduce the notebook's
approach with the Colab-only bits removed, but sample generation has since moved
off Piper entirely onto Google Cloud TTS (+ Edge TTS), with dedicated hard-negative
generation added on top — see below.

**Prerequisites (Windows → WSL2):**
- Enable CPU virtualization (Intel VT-x) in BIOS/UEFI.
- In elevated PowerShell: `wsl.exe --install --no-distribution`, then reboot.
- Install Ubuntu 22.04 (ships Python 3.10): `wsl --install -d Ubuntu-22.04`.

> On native Linux, skip the WSL steps. On native **Windows** (no WSL) it is harder —
> `pymicro-features` needs MSVC C++ Build Tools and TensorFlow is CPU-only — so
> WSL2 or Linux is strongly recommended.

**Environment setup (inside Ubuntu):** there's no single scripted installer for
this anymore (it evolved past the original `setup.sh`, now archived under
`local/Archive/`) — assembled here from what the current scripts actually need:
```bash
sudo apt update
sudo apt install -y python3.10-venv python3.10-dev build-essential \
    git wget unzip sox espeak-ng tmux
python3 -m venv ~/mww && source ~/mww/bin/activate

pip install --upgrade pip wheel
git clone -b november-update https://github.com/kahrendt/microWakeWord
# TF >= 2.16 / Keras 3 patch: model.evaluate() returns NumPy arrays already,
# so drop the redundant .numpy() calls train.py still has:
sed -i -E 's/((result|ambient_predictions)\["[a-z_]+"\])\.numpy\(\)/\1/g' \
  microWakeWord/microwakeword/train.py
pip install -e ./microWakeWord
pip install 'datasets<4.0' pymicro-features==1.0.0 tensorboard \
  google-cloud-texttospeech edge-tts
```
Copy the scripts onto the Linux filesystem (do NOT run from `/mnt/c` / OneDrive —
slow under WSL2, and OneDrive would try to sync intermediate training data):
```bash
cp -r /mnt/c/path/to/gemini-live-voice-assistant/04-wakeword/local ~/mww-local
cd ~/mww-local
sed -i 's/\r$//' *.sh *.py    # strip Windows CRLF line endings
```
Everything below runs from `~/mww-local` — scripts and generated data are
colocated there (no separate working directory).

**Google Cloud TTS credentials**: Application Default Credentials or a
service-account key via `GOOGLE_APPLICATION_CREDENTIALS`. **Do not** put a
service-account JSON key inside the repo folder — it's both git-tracked and
OneDrive-synced. Keep it outside the repo (e.g. `~/.config/gcloud/`) and point
`GOOGLE_APPLICATION_CREDENTIALS` at that external path.
```bash
export GOOGLE_APPLICATION_CREDENTIALS="/path/outside/the/repo/service-account.json"
```

**The pipeline** is organized into four stages. Run the first three in order
the first time; after that, only **Extend negative sample(s)** needs
repeating when you want to reinforce one more word.

#### Create baseline wakeword

Generates the positive wake-word clips and background/negative audio, then
trains a model with **no exposure to the curated hard-negative words yet**.
This baseline is what candidate negative words get scored against in the
next stage — a model that hasn't been taught to avoid a word shows you which
ones it confuses "naturally", instead of guessing from phonetic intuition.

1. `python create_samples.py <N>` — positive wake-word clips. Generates
   across 5 Google Cloud Chirp3-HD voices + 2 Edge TTS voices (7 total), each
   with randomized rate/pitch via SSML, then pitch-shifts every raw clip
   through 7 semitone offsets (`-4` to `+4`) via `sox` for further voice-timbre
   variety. Writes to `generated_samples/raw/` and `generated_samples/augmented/`.
   `python create_samples.py 1` plays back one test sample per voice instead
   of bulk-generating.
2. **(Recommended) Merge in real device recordings.** Synthetic TTS voices
   only get you so close to how the wake word actually sounds in your room,
   on your mic, in your voice. `04-wakeword/microWW/record_clips.py` records
   and auto-segments real utterances on the device:
   ```bash
   arecord -D pipewire -r 16000 -c 1 -f S16_LE -t raw - \
     | python record_clips.py --stdin --out real_clips
   python record_clips.py --review real_clips   # play/keep/delete each clip
   ```
   Copy the reviewed clips into the positive pool — `build_features.py`
   scans every `*.wav` in `generated_samples/augmented/`, so no code change
   is needed:
   ```bash
   cp real_clips/*.wav generated_samples/augmented/
   ```
   A few dozen real clips mixed into thousands of synthetic ones won't
   dominate training, but they give the model at least some exposure to a
   real voice/room/mic instead of purely clean TTS.
3. `python load_noise_stuff.py` — downloads background/negative audio: MIT
   RIRs, AudioSet, FMA, and microWakeWord's own negative-speech datasets.
   Skips whatever's already populated, so safe to re-run.
4. In `training_parameters.yaml`, set the `generated_negative_features`
   entry's `sampling_weight` to `0.0` (leave everything else as-is) — this
   keeps the curated hard negatives out of training for this baseline run,
   even before any have been generated.
5. `python build_features.py` — turns the above into spectrogram features
   (`generated_augmented_features/`, `generated_negative_features/`).
6. `bash train_microWW.sh` — trains the baseline model (see the notes under
   **Train wakeword** below for why you always run this script rather than
   hand-typing the training command).

#### Add negative samples

Generates candidate hard-negative clips, then keeps only the ones the
baseline model actually confuses with the wake word. Training against a word
the model was never going to mistake wastes the hard-negative sampling
budget and measurably does nothing.

1. `python create_negative_samples.py <N>` — hard-negative clips: curated
   Bulgarian phonetic near-misses to the wake word (e.g. "Точко", "Чочо"),
   common command words, and short syllables, same multi-voice + pitch-shift
   approach as positives. Writes to `generated_negatives/raw/` and
   `generated_negatives/augmented/`.
2. Scoring needs `pymicro-wakeword`, which is **permanently incompatible**
   with this training venv — it requires `pymicro-features>=2`, while
   microWakeWord's training code needs the old `1.0.0` API (`ProcessSamples`
   was renamed `process_samples` in 2.x). Installing it here silently
   upgrades `pymicro-features` and breaks `build_features.py` with
   `AttributeError: 'MicroFrontend' object has no attribute 'ProcessSamples'`.
   Use a separate venv instead, created once:
   ```bash
   python3 -m venv ~/mww-score
   source ~/mww-score/bin/activate
   pip install pymicro-wakeword google-cloud-texttospeech edge-tts
   deactivate
   ```
3. Hand-write a small JSON manifest pointing at the baseline `.tflite` from
   the previous stage — same shape as `04-wakeword/microWW/chochko.json`
   (only `model` needs to name your baseline `.tflite`; the exact
   `probability_cutoff` doesn't matter here since scoring reads the raw
   probability, not a pass/fail decision).
4. From `~/mww-local`, switch to the scoring venv to run the scorer, then
   switch back for everything else:
   ```bash
   source ~/mww-score/bin/activate
   python score_negative_clips.py --config baseline.json --dir generated_negatives/raw \
       --csv scores.csv --move-rejected generated_negatives/rejected_raw
   deactivate && source ~/mww/bin/activate
   ```
   This scores every raw clip against the baseline and moves (never
   deletes) the low scorers out of `raw/`.
5. `python create_negative_samples.py --pitch-only` — re-derives
   `augmented/` from whatever survived in `raw/`, without calling any TTS
   API again. (Back in `~/mww`, like all the non-scoring steps.)

`score_negative_words.py` is a companion script for the same job when you
don't have existing clips to score yet — it generates a couple of small
labeled probe clips per candidate word instead of scoring an existing pool.
Prefer `score_negative_clips.py` whenever a generated pool already exists.

#### Train wakeword

Restore the `generated_negative_features` entry's `sampling_weight` in
`training_parameters.yaml` to its real value (e.g. `5.0`), then rebuild and
train for real — now with only the pruned, genuinely-confusable hard
negatives included.

1. `python build_features.py` — **re-run this whenever the sample
   directories changed.** `train_microWW.sh` does not call it for you
   (deliberately, so you can retrain without regenerating features).
2. `bash train_microWW.sh` — trains directly from `training_parameters.yaml`
   + the feature dirs, using the tested `mixednet` architecture
   (`--mixconv_kernel_sizes` uses single-kernel blocks per block — mixed
   multi-kernel blocks were found to cause a large accuracy gap between the
   non-streaming trained model and the streaming-quantized tflite actually
   deployed, likely due to the extra channel-split/trim/concat machinery
   mixed kernels require). Wipes `trained_models/` and starts fresh every run.
   **Run this script itself rather than hand-typing the
   `microwakeword.model_train_eval` command** — doing so once with a
   different architecture (`inception`) and without the four `--test_*_0`
   disable flags the script sets got OOM-killed, since microwakeword's
   default is to run non-streaming TF eval, non-streaming tflite export,
   *and* non-streaming quantized tflite export in addition to whatever
   streaming test you asked for — that stacks up fast under WSL2's memory
   ceiling.

#### Extend negative sample(s)

Ongoing maintenance once the model is otherwise working: add one more word
you're already confident is a hard negative, without repeating the scoring
stage.

1. Add the word to `NEGATIVE_WORDS` in `create_negative_samples.py`.
2. `python create_negative_samples.py <N> "new word"` — generates exactly
   `N` new clips per voice, restricted to that one word. Each voice picks up
   from its own actual last index (scanned from `raw/`, not a count you have
   to work out yourself), so this stays correct even after pruning left
   uneven, gappy survivor counts per voice — no manual index math needed.
   Pitch-shifts the new clips into `augmented/` in the same run.
3. `python build_features.py` → `bash train_microWW.sh`, same as **Train
   wakeword** above.

If you're not sure a candidate word is actually confusable, use (from the
separate `~/mww-score` venv — see **Add negative samples** above)
`score_negative_words.py --config model.json --words "new word"` instead of
skipping straight to step 1 — it generates a couple of labeled probe clips
and scores them so you don't add dead weight to the negative set.

**Output**: the model lands at (inside wherever you ran `train_microWW.sh` from):
```
trained_models/wakeword/tflite_stream_state_internal_quant/stream_state_internal_quant.tflite
```
Copy it back to Windows:
```bash
cp trained_models/wakeword/tflite_stream_state_internal_quant/stream_state_internal_quant.tflite \
   /mnt/c/Users/<you>/Downloads/
```
As with the Colab path, to use it in ESPHome (or with `test_mww.py`) you still
need a JSON model manifest — see the [ESPHome documentation](https://esphome.io/components/micro_wake_word) and the
[model repo examples](https://github.com/esphome/micro-wake-word-models/tree/main/models/v2).

**Notes / knobs:**
- **Memory**: WSL2 defaults to capping itself at ~50% of host RAM. If you hit
  an OOM `Killed` even with `train_microWW.sh`'s tested `mixednet` config,
  raise the cap in `%UserProfile%\.wslconfig` (`[wsl2]` / `memory=24GB`, then
  `wsl --shutdown` and restart), or lower `batch_size` in
  `training_parameters.yaml` (128 → 64), or drop a negative set from its
  `features` list.
- **Speed**: expect roughly an hour-ish-plus for training on CPU; it prints a
  metrics line every 500 steps, so you can watch progress. Sample generation
  time now depends on Cloud/Edge TTS API latency/quota rather than local
  compute.
- **No resume**: `train_microWW.sh` wipes `trained_models/` at the start of
  every run — each run trains from scratch, it doesn't continue a previous
  checkpoint.
- **`config.yaml` vs `training_parameters.yaml`**: if you see a `config.yaml`
  sitting in the working dir, it's not used by anything — its schema
  (`target_phrase`, `positive_data_paths`, `epochs`, ...) doesn't match what
  `microwakeword.model_train_eval` actually reads. `training_parameters.yaml`
  is the real config, and it's edited by hand now (not regenerated by a
  script) — check it directly if a run behaves unexpectedly.
- **No `ambient_noise/` directory**: this is expected, not missing anything.
  `load_noise_stuff.py` produces `mit_rirs/`, `audioset_16k/`, `fma_16k/`
  (plus a raw `fma/` intermediate), and `negative_datasets/` — that's the
  complete set.

---
[Return to Main README](../README.md)

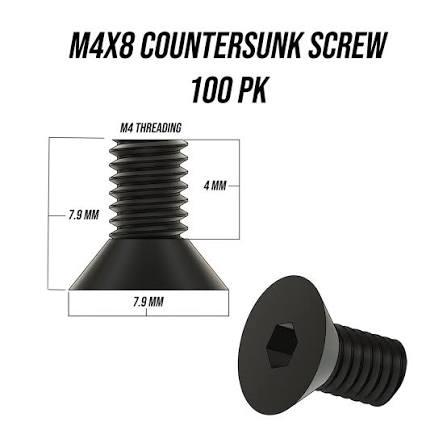
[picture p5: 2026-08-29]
06-enclosure/images/countersink-screw.png

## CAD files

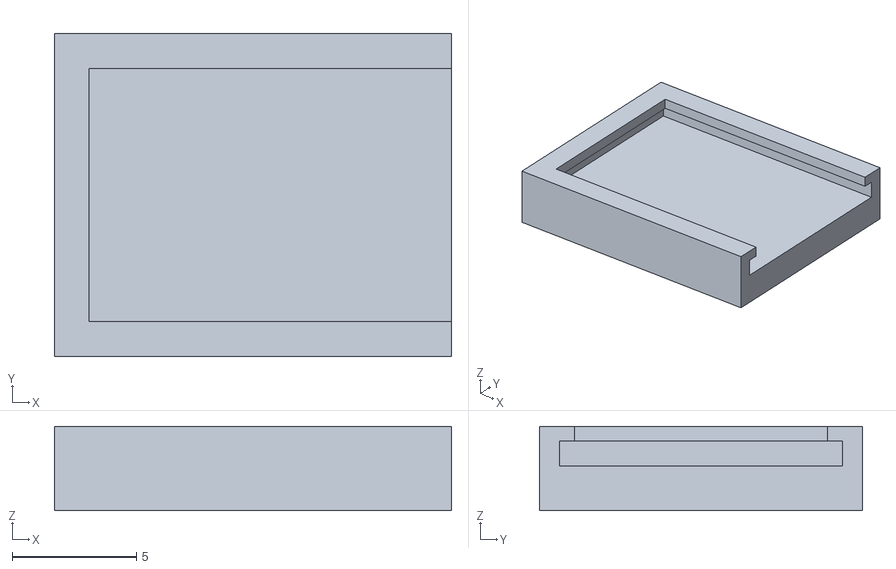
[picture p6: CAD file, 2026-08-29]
06-enclosure/VA-Button bed.stl
16.0 x 13.0 x 3.40

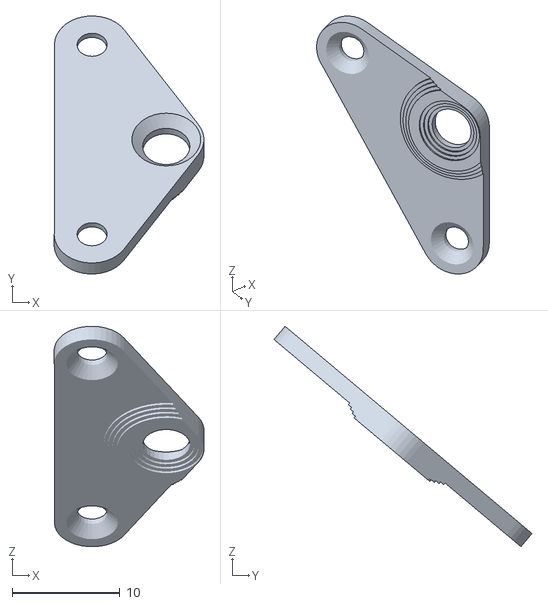
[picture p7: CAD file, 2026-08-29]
06-enclosure/VA-PCB leg.stl
13.9 x 24.0 x 20.5

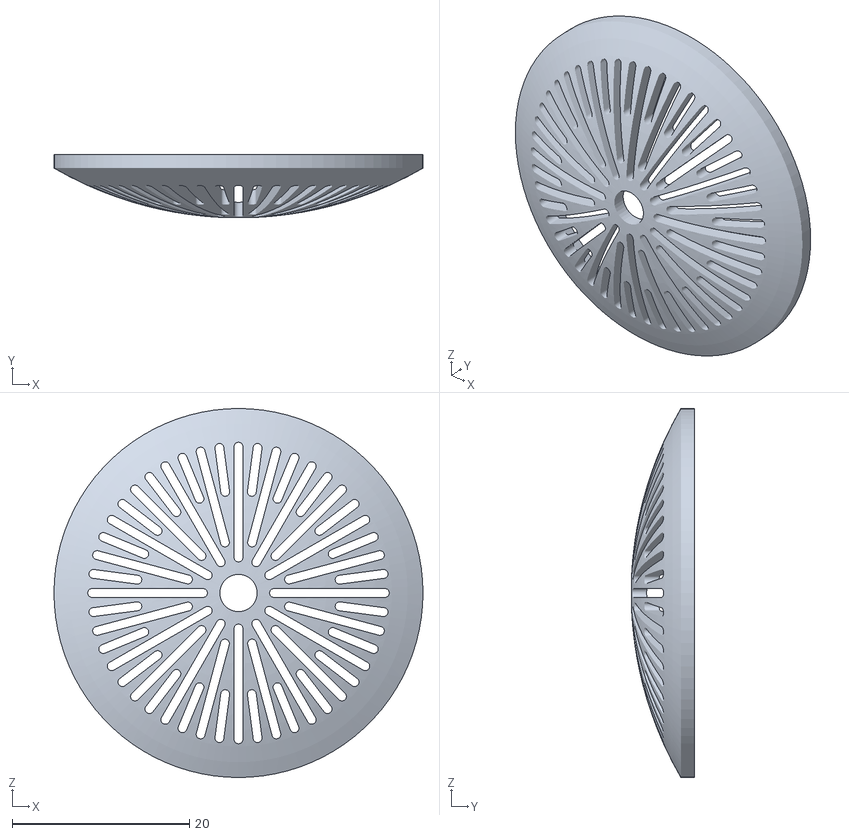
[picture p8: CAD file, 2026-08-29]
06-enclosure/VA-Speaker grill.stl
41.6 x 7.08 x 41.6

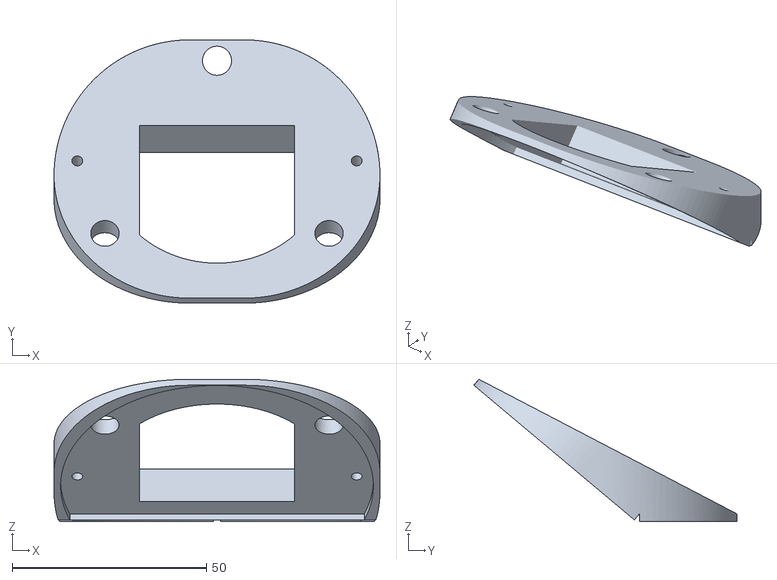
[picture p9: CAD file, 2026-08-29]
06-enclosure/VA-Stencil to glue.stl
84.0 x 67.9 x 36.7

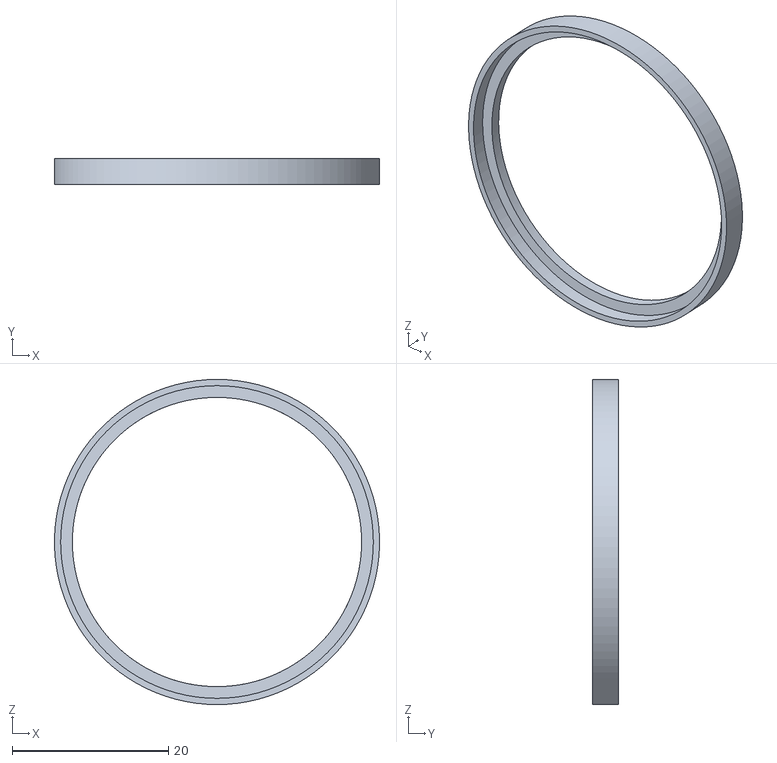
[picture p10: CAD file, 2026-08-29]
06-enclosure/VA-O-ring.stl
41.6 x 3.27 x 41.6

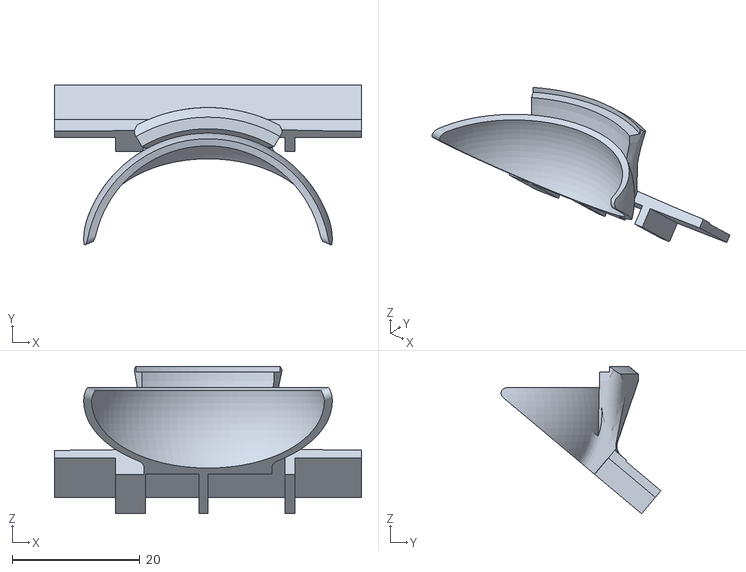
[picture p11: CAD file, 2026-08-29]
06-enclosure/VA-Mirror.stl
48.0 x 25.0 x 23.1

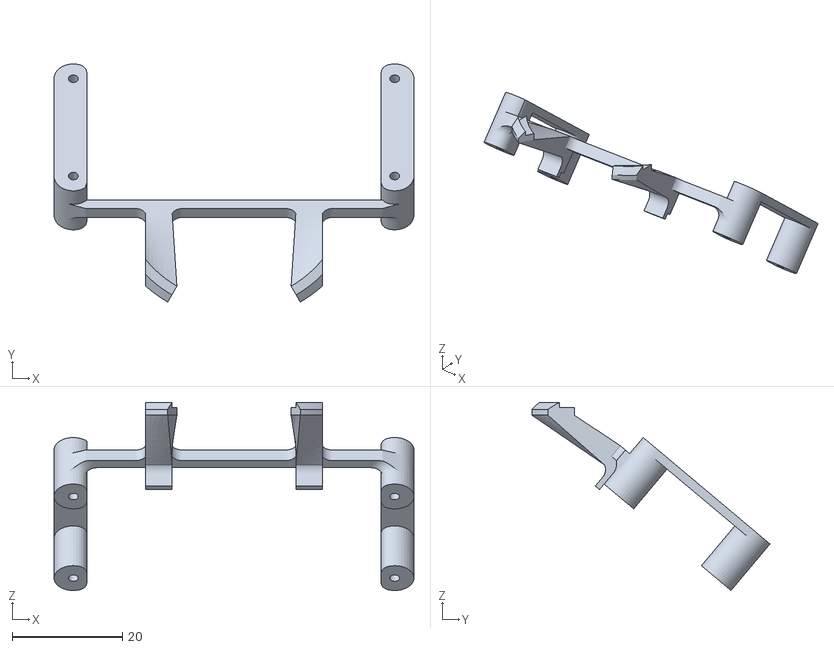
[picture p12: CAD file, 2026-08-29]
06-enclosure/VA-PCB holder.stl
65.2 x 43.1 x 34.1

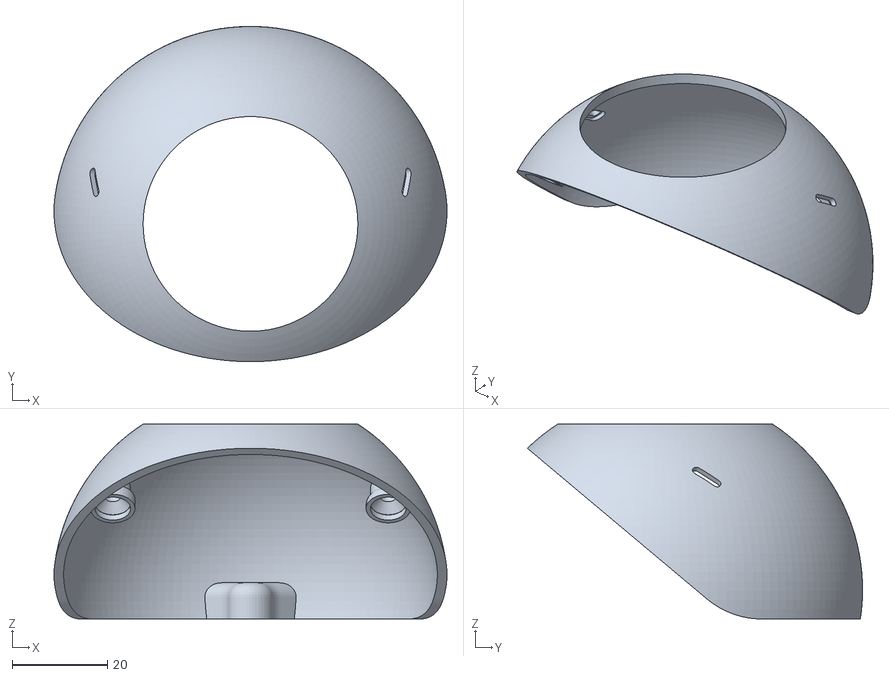
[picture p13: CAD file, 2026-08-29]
06-enclosure/VA-Middle.stl
82.4 x 70.3 x 40.9

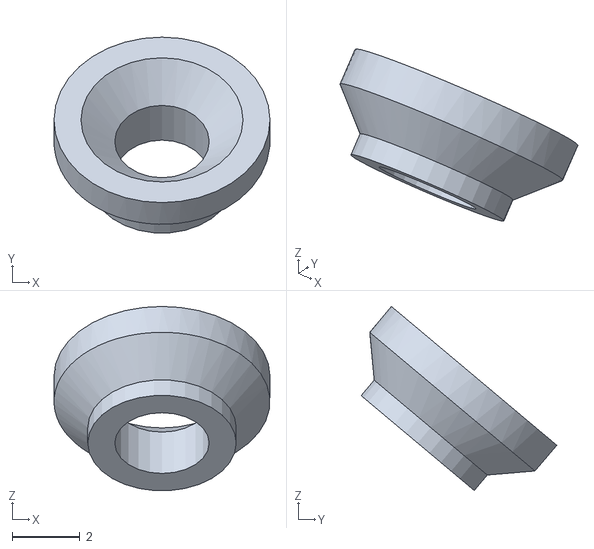
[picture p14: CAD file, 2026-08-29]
06-enclosure/VA-PCB leg gasket.stl
6.40 x 5.80 x 5.45

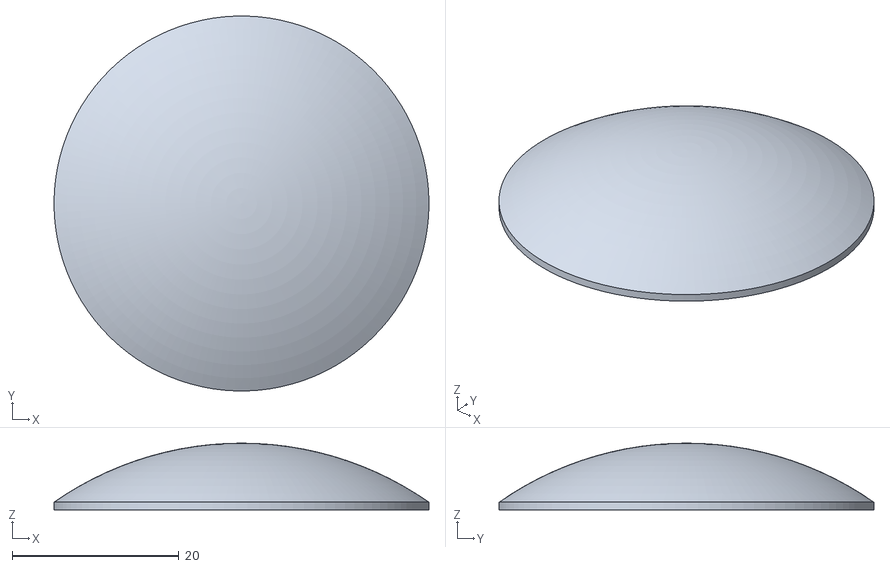
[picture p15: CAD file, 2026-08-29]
06-enclosure/VA-Top.stl
45.0 x 45.0 x 8.01

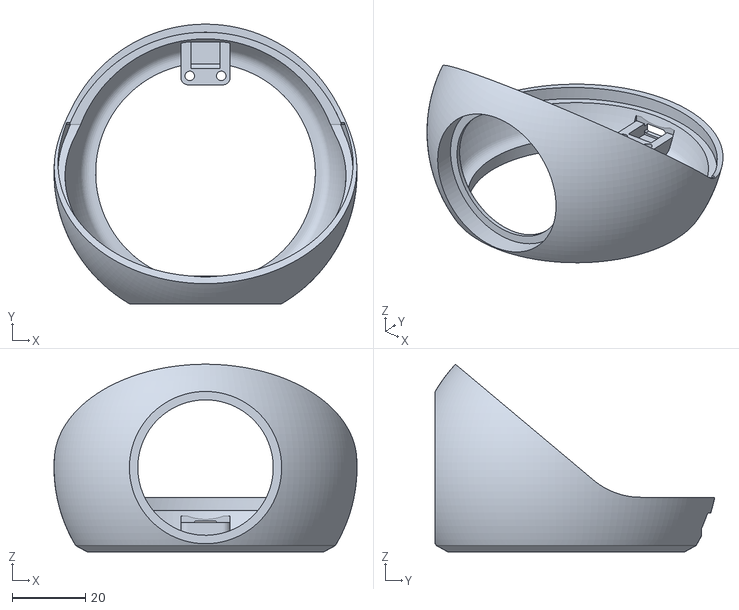
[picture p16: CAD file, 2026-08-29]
06-enclosure/VA-Base.stl
82.8 x 76.4 x 51.2

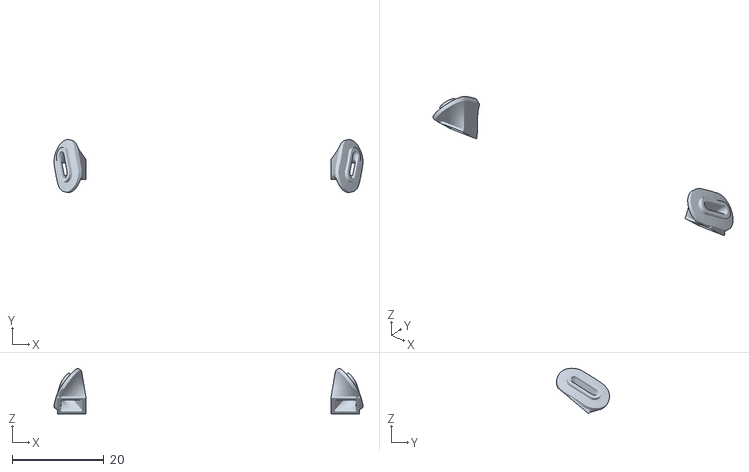
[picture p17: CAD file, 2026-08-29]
06-enclosure/VA-Mic tubes.stl
67.2 x 11.6 x 9.91

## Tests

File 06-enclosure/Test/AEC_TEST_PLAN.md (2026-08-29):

# Test plan — Pi + ReSpeaker v2.0 (TLV320AIC3104) enclosure / PipeWire AEC

Two symptoms to explain:

- **S1** — AEC removes far more than the echo: over half the near-end speech disappears.
- **S2** — Added noise and whistles in the AEC output.

They may have the same root cause or two different ones. The plan is ordered so that
each phase eliminates whole branches. **Do not skip ahead**: several later phases are
meaningless if an earlier one hasn't been cleared, and tuning suppression on top of a
broken linear filter is the classic way to spend a week going in circles.

Tools: `enclosure_probe.py` (echo path physics), `aec_score.py` (end-to-end KPIs).

---

## Rules for the whole campaign

1. **One variable per run.** Never change the enclosure and the config in the same step.
2. **Freeze the rig.** Tape-mark the talker speaker position, the enclosure position,
   and the surface it stands on. Record every level in the log. A run taken with
   different geometry is not comparable to anything.
3. **Log everything** in `runs/<tag>/` with a one-line note on what changed.
4. **Re-run the previous best config** every ~10 runs as a drift check. If it no longer
   reproduces, something in the rig moved and the intervening results are suspect.
5. Never measure S1/S2 by ear as the primary signal. Ears are for noticing; the
   numbers are for deciding.

### Headline KPIs (from `aec_score.py`)

| KPI | Meaning | Target | Fail |
|---|---|---|---|
| `erle_db` | echo attenuation, far-end single-talk | > 30 | < 20 |
| `retention_db` | near-end speech surviving double-talk | > −3 | < −8 |
| `whistle_index` | musical-noise indicator | < 2 | > 4 |

`retention_db` is the number that corresponds to S1. `whistle_index` corresponds to S2.

---

## Phase 0 — Build the rig and get a baseline

**Goal:** make the problem measurable before touching anything.

1. Obtain a second, **wired** speaker as the artificial talker (cheap USB speaker;
   Bluetooth is unusable, its latency wanders). Fix it 50 cm from the enclosure, tape-marked.
2. Identify all four PipeWire nodes:
   ```bash
   pw-cli ls Node | grep -E "node.name|node.description"
   ```
   You need: the AEC sink, the AEC source, the raw `seeed2micvoicec` input, the talker output.
3. Force unity gain on both capture nodes so raw and AEC paths are comparable:
   ```bash
   wpctl set-volume <raw-source-id> 1.0
   wpctl set-volume <aec-source-id> 1.0
   ```
4. Baseline run, current config untouched:
   ```bash
   python3 aec_score.py run --tag 00-baseline \
     --enclosure-out <aec-sink> --talker-out <usb> \
     --in-aec <aec-source> --in-raw <raw-source>
   ```
5. Save `mixer_dump.txt`, your PipeWire conf, `pw-top` output, and `uname -a`.

**Gate 0:** you now have `erle_db`, `retention_db`, `whistle_index`. Everything
afterwards is judged against these three numbers.

- If `erle_db` is already > 30 and only `retention_db` is bad → the linear filter is
  fine and this is purely a suppression/NS/AGC tuning problem. **Jump to Phase 5**,
  then come back to Phase 3 only if Phase 5 can't fix it.
- Otherwise continue in order.

---

## Phase 1 — Is it even acoustic?

**Goal:** rule out electrical noise before spending any effort on the enclosure.
S2 in particular has a strong electrical candidate.

Run `enclosure_probe.py silence` in each condition, 30 s each:

| Run | Condition |
|---|---|
| 1a | Everything normal, nothing playing |
| 1b | Speaker unplugged from the JST connector |
| 1c | APA102 LEDs driven off / their driver disabled |
| 1d | Pi under heavy CPU load (`stress-ng --cpu 4`) |
| 1e | Pi on battery / different PSU, WiFi disabled |

Compare the listed narrowband tones across runs.

**Gate 1:**
- **Tones present in 1a and unchanged in 1b** → not acoustic. The whistles are EMI or
  supply noise coupling into the mic preamps. → **Branch E** below. S2 is solved
  there and you return to Phase 2 for S1 only.
- **Tones present in 1a, gone in 1b** → the amplifier or its supply is the source
  (switching noise, or the amp self-oscillating into a reactive load). → **Branch E**.
- **Tones appear only in 1c or 1d** → LED driver or CPU/DC-DC coupling. → **Branch E**.
- **No tones anywhere; floor is broadband and low** → S2 is genuinely being *created*
  by the AEC's noise suppressor. Continue to Phase 2; expect Phase 5 to fix S2.

> **Branch E (electrical):** separate the analogue ground return of the speaker from the
> mic ground; add series ferrite and an RC snubber at the speaker terminals; keep speaker
> wiring away from the mic traces and out of parallel runs; power the Pi from a linear
> supply for the duration of the test to confirm. Re-run 1a until clean, then rejoin at Phase 2.

---

## Phase 2 — Codec configuration audit

**Goal:** eliminate the AIC3104's own processing, which can defeat an AEC entirely.

1. `amixer -c seeed2micvoicec contents > mixer_dump.txt`
2. Disable the hardware AGC/ALC on both ADC channels. Look for `AGC`,
   `AGC Target Level`, `AGC Max PGA`, `AGC Attack/Decay Time`, `ALC`.
3. Mute every analogue bypass into the output mixers (`Line2L → HPLOUT`,
   `PGA → LOP`, `LINE1L Playback`, etc.). Only `DAC → Output Mixer` stays live.
4. Disable de-emphasis and any digital effects biquads in the DAC path.
5. Set the mic PGA to a **fixed** value. Pin the sample rate to 48 kHz on both the
   card and PipeWire (`default.clock.allowed-rates = [ 48000 ]`).
6. `alsactl store`, restart PipeWire, re-run `aec_score.py run --tag 02-codec-clean`.

**Gate 2:**
- **`retention_db` improves by more than 4 dB** → the hardware AGC was the primary
  cause of S1. A time-varying, undeclared mic gain makes the adaptive filter
  unconvergeable. Confirm by re-enabling it alone and watching the number go back.
  Then re-baseline and reconsider whether Phases 3–4 are still needed.
- **`erle_db` improves sharply** → you had an analogue bypass path competing with the
  acoustic one and confusing the delay estimator.
- **Nothing changes** → continue to Phase 3.

---

## Phase 3 — Linearity vs. drive level

**Goal:** find the level at which the output stage or driver stops being linear.
This caps ERLE no matter what you do in software, and is my leading hypothesis.

```bash
for A in 0.03 0.06 0.12 0.25 0.5 0.8; do
  python3 enclosure_probe.py sweep --amp $A --out lvl_$A \
    --in-dev <raw> --out-dev <raw>
done
```

Plot `harmonic_to_linear_db["2"]` and `["3"]` against amplitude.

**Gate 3:**
- **A clear knee exists** (distortion rises steeply past some amplitude) → set your
  operating level 6 dB below the knee, re-run `aec_score.py --tag 03-level-backoff`,
  and see how much of S1 that alone recovers. This is a free fix — no hardware change.
- **Harmonics worse than −25 dB even at 0.03** → something is distorting at all levels:
  ADC clipping (lower the PGA and repeat), a mechanical rattle, or the driver being
  driven through a DC-blocking capacitor that's too small. Investigate before continuing.
- **Harmonics better than −35 dB across the range** → linearity is fine, the echo path
  is not the problem. **Skip Phase 4's damping work** and go to Phase 4 for the tail
  measurement only, then to Phase 5.

Also note whether backing off the level changes `whistle_index`. If it does, S2 is
downstream of distortion, not an independent problem.

---

## Phase 4 — Echo path structure

**Goal:** characterise the tail and find out which mechanical part causes it.
Run everything at the operating level fixed in Phase 3.

### 4.1 Baseline path

```bash
python3 enclosure_probe.py sweep --amp <operating> --out 04-assembled
python3 enclosure_probe.py noise --amp <operating>
```

Record: `bulk_delay_ms`, `erl_db`, `t20_ms`, `t30_ms`, `band_erl_db`, coherence per band.

**Gate 4.1:**
- `t30_ms` < 40 **and** coherence > 0.97 across 300–3400 Hz → the enclosure is not your
  problem. **Skip 4.2 and Phase 6 entirely** and go to Phase 5.
- `t30_ms` > 60 → the tail exceeds what AEC3's adaptive filter covers. Damping work is
  mandatory; continue to 4.2.
- Coherence dips in a narrow band → note the frequencies, they'll match the bumps in
  `band_erl_db` and identify which resonator is responsible.

### 4.2 Path decomposition

Four sweeps, identical level, identical mic gain:

| Run | Configuration | Isolates |
|---|---|---|
| 4.2a | Fully assembled (= 4.1) | reference |
| 4.2b | Top half detached, on foam, 200 mm away, wires extended | pure airborne |
| 4.2c | Assembled, TPU legs replaced with soft foam blocks | the legs' contribution |
| 4.2d | Assembled, ReSpeaker PCB on silicone grommets inside the dome | board mounting |

Compute per-band deltas (a−b), (a−c), (a−d).

**Gate 4.2** — attribute the tail:
- **(a−c) large, especially 100–400 Hz** → the TPU legs are transmitting, and probably
  resonating rather than isolating. → Phase 6 item *legs*.
- **(a−b) large above 1.5 kHz with narrow peaks** → the steel ring and/or dome are
  ringing. → Phase 6 items *ring damping*, *dome lining*.
- **(a−d) large** → the PCB is rigidly coupled; cheapest fix in the whole project.
  → Phase 6 item *PCB isolation*.
- **All deltas small but `t30` still high** → the ring-down is inside the sealed
  bottom volume, i.e. it's the box itself. Add internal damping material to the baffle
  enclosure.

---

## Phase 5 — PipeWire, one knob at a time

**Goal:** find the minimum processing that meets the KPIs. Do this **after** the
physical path is as good as it's going to get, or the tuning will be optimised for a
problem you're about to change.

Start from AEC-only: `noise_suppression=false`, `gain_control=false`,
`analog_gain_control=false`, `digital_gain_control=false`, `voice_detection=false`,
`high_pass_filter=true`, `extended_filter=false`, `node.latency = 480/48000`.

| Run | Change |
|---|---|
| 5a | AEC only (above) |
| 5b | 5a + `high_pass_filter=false` |
| 5c | best of 5a/5b + `voice_detection=true` |
| 5d | best so far + `noise_suppression=true` |
| 5e | best so far + `digital_gain_control=true` |
| 5f | best so far + `extended_filter=true` |
| 5g | best so far, `node.latency = 960/48000` |

```bash
python3 aec_score.py compare 05a 05b 05c 05d 05e 05f 05g
```

**Gate 5:** keep a setting **only if it improves at least one KPI without degrading
another by more than 1 dB.** Expected pattern given your symptoms: 5d and 5e each cost
several dB of `retention_db`, and 5d raises `whistle_index` sharply. If so, S1 and S2
are both suppression artefacts and the answer is to leave NS and AGC off here and do
noise reduction downstream in a separate `module-filter-chain` where it can't interact
with the echo estimate.

If `erle_db` is still < 25 with everything off, the AEC is not converging and no
combination of these flags will help — go back to Phase 3/4 results.

---

## Phase 6 — Mechanical fixes

Only the items Gate 4.2 pointed at. **One at a time**, re-running 4.1 after each.

| Fix | Do it | Expect |
|---|---|---|
| Ring damping | butyl tape + thin constraining strip, or pot the inner channel | narrow `band_erl_db` peaks flatten; `t30` drops |
| PCB isolation | silicone grommets, board floating in the dome | broadband `t30` drop, best effort/benefit ratio |
| Dome lining | open-cell foam or wool felt against the inner wall | HF tail and cavity modes drop |
| Leg retune | thinner / hourglass-waisted legs, softer TPU (60–70A), or added top mass | LF transmission drops; target isolation resonance < 70 Hz |
| Leak check | smoke or soapy water around leg mounts at high excursion | removes level-dependent chuffing |

**Gate 6:** stop when `t30_ms` < 40 and coherence > 0.97 in 300–3400 Hz, or when a fix
returns less than 3 dB. Then **re-run Phase 5 from scratch** — the optimal software
settings change once the physical path changes.

---

## Phase 7 — Soak and regression

1. 30-minute continuous run; count xruns in `pw-top`.
2. Drift check: 10-minute simultaneous playback and capture, compare the sample offset
   of a click at the start and at the end. Should be ~0 (single codec, shared clock).
   Non-zero means something is resampling and must be found.
3. Re-convergence: stop and restart playback 20 times; measure how long `erle_db`
   takes to recover each time.
4. Thermal: repeat the Phase 0 baseline after an hour of running. PLA creeps and TPU
   softens; a fix that depends on leg stiffness may not hold.

---

## Reporting checkpoints

Stop and reassess the plan after each of these, rather than running straight through:

- **After Gate 0** — the three baseline numbers decide whether this is a hardware or a
  software campaign, and may let you skip Phases 3, 4 and 6 entirely.
- **After Gate 1** — decides whether S2 is a separate electrical problem.
- **After Gate 2** — the AGC result may end the investigation on its own.
- **After Gate 3** — a distortion knee gives you a free fix and re-frames everything after.
- **After Gate 4.2** — tells you which mechanical work is worth doing and which isn't.
- **After Gate 5** — if the KPIs are met, stop. Phase 6 is only worth doing if they aren't.

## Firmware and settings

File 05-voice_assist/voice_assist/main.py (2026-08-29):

# main.py
#
# Voice Assistant project
#
import logging

# ── Logging configuration ──────────────────────────────────────────
DEBUG = False   # Set to True for full debug output with timestamps

class LevelFormatter(logging.Formatter):
    """
    DEBUG=False: INFO → message only, WARNING/ERROR → with timestamp
    DEBUG=True:  all messages → full format with timestamp
    """
    _simple = logging.Formatter('%(message)s')
    _full   = logging.Formatter(
        '%(asctime)s %(levelname)-8s %(name)s: %(message)s'
    )

    def format(self, record):
        if not DEBUG and record.levelno == logging.INFO:
            return self._simple.format(record)
        return self._full.format(record)

_handler = logging.StreamHandler()
_handler.setFormatter(LevelFormatter())
logging.getLogger().setLevel(logging.DEBUG if DEBUG else logging.INFO)
logging.getLogger().addHandler(logging.NullHandler())  # suppress default
logging.getLogger().addHandler(_handler)

log = logging.getLogger(__name__)

import asyncio
import signal
import subprocess
import numpy as np

import config
import leds
import chimes
from capture import MicCapture
from playback import Speaker
from wakeword import create_detector
from gemini import GeminiLiveClient
from spotify import SpotifyController
from smarthome import SmartHome
from button import Button

class VoiceAssistant:
    def __init__(self):
        self.state   = 'IDLE'
        self.loop    = None

        self.mic      = MicCapture()
        self.speaker  = Speaker()

        self.wakeword = create_detector(model_path=config.WAKEWORD_MODEL)
        self.button   = Button()
        self.gemini   = None
        self.spotify  = SpotifyController()
        self.smarthome = SmartHome()

        self._dialog_task    = None
        self._end_event      = None
        self._last_activity  = 0.0
        self._gemini_speaking = False
        self._end_after_turn = False
        self._volume         = 100
        self._VOLUME_STEP    = 15
        self._spotify_ducked = False

    def setup(self, loop: asyncio.AbstractEventLoop):
        self.loop = loop

        # Build system prompt with location — called once at startup
        try:
            import location as loc_module
            loc     = loc_module.get_current()
            loc_str = loc_module.format_for_prompt(loc)
            config.GEMINI_SYSTEM += loc_str
            log.info(f'Location: {loc_str}')
        except Exception as e:
            log.warning(f'Location unavailable: {e}')

        self.wakeword.set_loop(loop)
        self.wakeword.set_on_detect(self._on_wake)

        self.button.set_loop(loop)
        self.button.set_on_press(self._on_wake)

        self.speaker.start()
        chimes.set_speaker(self.speaker)

        self.mic.start()
        self.button.start()

        self.smarthome.connect()
        if self.smarthome.connected:
            log.info('Home Assistant ready')
        else:
            log.info('Home Assistant not available')

        self.spotify.connect()
        if self.spotify.connected:
            log.info('Spotify ready')
        else:
            log.info('Spotify not available')

        log.info('VoiceAssistant ready')

    def teardown(self):
        log.info('Shutting down...')
        self.mic.stop()
        self.speaker.stop()
        self.button.stop()
        leds.off()
        log.info('Shutdown complete')

    # ── IDLE ──────────────────────────────────────────────────────────

    def enter_idle(self):
        self.state = 'IDLE'
        log.info('State: IDLE')
        self.mic.clear_consumers()
        self.mic.add_consumer(self._wakeword_consumer)
        self.button.set_on_press(self._on_wake)
        leds.idle()

    def _wakeword_consumer(self, pcm_i16: np.ndarray):
        self.wakeword.process(pcm_i16)
        
    def _on_gemini_audio_consumer(self, pcm_i16: np.ndarray):
        """Mic consumer during dialog — resets timeout while user speaks."""
        if self.gemini is None:
            return
        self.gemini.send_audio(pcm_i16)

    def _on_wake(self):
        if self.state != 'IDLE':
            log.info('Wake ignored — already in DIALOG')
            return
        log.info('Wake word detected!')
        self._dialog_task = asyncio.create_task(self._run_dialog())

    # ── DIALOG ────────────────────────────────────────────────────────

    async def _run_dialog(self):
        self.state         = 'DIALOG'
        self._dialog_start = self.loop.time()
        self._end_event    = asyncio.Event()
        self._end_after_turn = False
        log.info('State: DIALOG')

        # Set button to end dialog IMMEDIATELY
        self.button.set_on_press(self._request_end_dialog)

        # Play chime first
        chimes.wake_detected()
        leds.dialog()

        # Duck Spotify — run in thread with timeout.
        # IMPORTANT: only if it's already playing ON Chochko. set_volume()
        # calls _ensure_active(), which transfers playback to Chochko if
        # some OTHER device is currently active — so checking get_current()
        # alone (account-wide "is anything playing") isn't enough: it would
        # hijack playback from e.g. a PC just because the wake word fired,
        # even for a completely unrelated request.
        self._spotify_ducked = False
        if self.spotify.connected:
            try:
                current = await asyncio.wait_for(
                    self.loop.run_in_executor(None, self.spotify.get_current),
                    timeout=3.0
                )
                if current and current.get('playing'):
                    device = await self.loop.run_in_executor(
                        None, self.spotify.get_current_playback_device
                    )
                    if device and 'chochko' in (device.get('name') or '').lower():
                        await self.loop.run_in_executor(
                            None, self.spotify.set_volume, 75
                        )
                        self._spotify_ducked = True
                    else:
                        log.info('Spotify playing on another device — not ducking/transferring')
            except asyncio.TimeoutError:
                log.warning('Spotify timeout — skipping duck')
            except Exception as e:
                log.warning(f'Spotify error — skipping duck: {e}')

        ha_devices = self.smarthome.list_devices() if self.smarthome.connected else []

        self.gemini = GeminiLiveClient(
            on_audio=self._on_gemini_audio,
            on_turn_complete=self._on_turn_complete,
            on_interrupted=self._on_interrupted,
            on_text=self._on_gemini_text,
            on_tool_call=self._on_tool_call,
            spotify_connected=self.spotify.connected,
            ha_connected=self.smarthome.connected,
            ha_devices=ha_devices,
        )

        try:
            await asyncio.wait_for(self.gemini.connect(), timeout=10.0)
            log.info('Gemini connected')
            self.mic.clear_consumers()
            self.mic.add_consumer(self._on_gemini_audio_consumer)
            await self._dialog_loop()

        except asyncio.TimeoutError:
            log.error('Gemini connect timeout')
            chimes.error()
            leds.error()
            await asyncio.sleep(1)

        except Exception as e:
            log.error(f'Dialog error: {e}')
            chimes.error()
            leds.error()
            await asyncio.sleep(1)

        finally:
            await self._end_dialog()

    async def _dialog_loop(self):
        """Keep dialog alive until button, timeout, or turnComplete signal."""
        WATCHDOG = 120  # absolute maximum 2 minutes
        
        self._last_activity   = self.loop.time()
        self._gemini_speaking = False

        while not self._end_event.is_set():
            await asyncio.sleep(0.5)
            now  = self.loop.time()
            idle = now - self._last_activity

            # Watchdog
            if now - self._dialog_start > WATCHDOG:
                log.warning('Dialog watchdog — forcing IDLE')
                break

            # Timeout only when Gemini not speaking
            if not self._gemini_speaking:
                if idle > config.DIALOG_TIMEOUT:
                    log.info(f'Dialog timeout after {config.DIALOG_TIMEOUT}s')
                    break

    def _request_end_dialog(self):
        log.info('Button pressed — ending dialog')
        if self._end_event:
            self._end_event.set()
        else:
            log.warning('_end_event is None — scheduling force idle')
            asyncio.create_task(self._force_idle())

    async def _force_idle(self):
        """Emergency recovery if _end_event missing."""
        log.warning('Force idle recovery')
        if self.gemini:
            await self.gemini.disconnect()
            self.gemini = None
        self.speaker.clear()
        self.mic.set_mute(False)
        chimes.dialog_ended()
        self.wakeword.reset(cooldown=1.0)
        await asyncio.sleep(1.0)
        self.enter_idle()

    def _on_gemini_audio(self, pcm_24k: bytes):
        self._gemini_speaking = True
        self._last_activity   = self.loop.time()
        self.speaker.play_gemini(pcm_24k)

    def _on_turn_complete(self):
        self._gemini_speaking = False
        self._last_activity   = self.loop.time()
        log.info('Gemini turn complete — listening...')
        if self._end_after_turn:
            self._end_after_turn = False
            if self._end_event:
                self._end_event.set()

    def _on_interrupted(self):
        self._gemini_speaking = False
        self.speaker.clear()
        self._last_activity = self.loop.time()
        log.info('Gemini interrupted by user')

    def _on_gemini_text(self, text: str):
        log.info(f'Gemini: {text}')

    def _on_tool_call(self, calls: list):
        responses  = []
        scheduling = None

        for call in calls:
            name    = call.get('name', '')
            args    = call.get('args', {})
            call_id = call.get('id', '')
            result  = 'OK'

            if name == 'set_address':
                import location
                loc     = location.get_current()
                address = args.get('address', '')
                location.save_address(address, loc['country'], loc['town'])
                log.info(f'Address saved: {address}')
                result = 'Адресът е запазен.'

            elif name == 'set_volume':
                action = args.get('action', '').lower()
                result = self._handle_volume(action)

            elif name == 'get_weather':
                import weather, location
                town = args.get('town', '')
                if not town:
                    loc     = location.get_current()
                    town    = loc.get('town', '')
                    country = loc.get('country', '')
                else:
                    country = ''
                w      = weather.get_weather(town, country)
                result = weather.format_for_gemini(w)
                log.info(f'Weather: {result}')

            elif name == 'play_music':
                query = args.get('query', '')
                self.loop.run_in_executor(None, self.spotify.play, query)
                result               = f'Пускам {query}' if query else 'Продължавам музиката.'
                self._end_after_turn = True

            elif name == 'next_track':      
                self.loop.run_in_executor(None, self.spotify.next_track)
                result               = 'Следваща песен.'
                self._end_after_turn = True   # end after Gemini confirms

            elif name == 'previous_track':
                self.loop.run_in_executor(None, self.spotify.previous_track)
                result               = 'Предишна песен.'
                self._end_after_turn = True

            elif name == 'pause_music':
                self.loop.run_in_executor(None, self.spotify.pause)
                result               = 'Музиката е на пауза.'
                self._end_after_turn = True

            elif name == 'resume_music':
                self.loop.run_in_executor(None, self.spotify.resume)
                result               = 'Продължавам музиката.'
                self._end_after_turn = True

            elif name == 'transfer_music':
                device_name          = args.get('device_name', '')
                result               = self.spotify.transfer(device_name)
                self._end_after_turn = True

            elif name == 'end_dialog':
                result               = 'Дочуване!'
                self._end_after_turn = True
                scheduling           = 'WHEN_IDLE'

            elif name == 'ha_control':
                result = self._handle_ha(args)
                scheduling = 'INTERRUPT'

            log.info(f'Tool {name}: {result}')
            responses.append({
                'id':     call_id,
                'name':   name,
                'result': result
            })

        if self.gemini and responses:
            self.gemini.send_tool_responses(responses)

    # Below this raw ALSA "Master" percentage, this hardware is inaudible —
    # the control's raw 0-100 range isn't perceptually linear, so the bottom
    # chunk of it does nothing audible. Rescale the user-facing 0-100%
    # onto [MASTER_MIN_PCT, 100] instead of [0, 100], so "quiet" still means
    # something audible rather than silence. Tune by ear: raise if the low
    # end is still too quiet, lower if it's now too loud at the bottom.
    MASTER_MIN_PCT = 33

    def _handle_volume(self, action: str) -> str:
        def pct_to_raw(pct: int) -> int:
            if pct <= 0:
                return 0
            span = 100 - self.MASTER_MIN_PCT
            return round(self.MASTER_MIN_PCT + span * (pct / 100))

        def set_master(pct: int) -> int:
            pct = max(0, min(100, pct))
            raw = pct_to_raw(pct)
            subprocess.run(
                ['amixer', 'sset', 'Master', f'{raw}%'],
                capture_output=True
            )
            self._volume = pct
            log.info(f'Volume: {pct}% (raw Master {raw}%)')
            return pct

        if action == 'louder':
            v = set_master(self._volume + self._VOLUME_STEP)
            return f'Звукът е увеличен на {v}%.'
        elif action == 'quieter':
            v = set_master(self._volume - self._VOLUME_STEP)
            return f'Звукът е намален на {v}%.'
        elif action == 'max':
            set_master(100)
            return 'Максимален звук.'
        elif action == 'mute':
            subprocess.run(['amixer', 'sset', 'Master', '0%'],
                           capture_output=True)
            return 'Звукът е изключен.'
        elif action == 'unmute':
            v = set_master(self._volume)
            return f'Звукът е включен на {v}%.'
        return 'Непозната команда за звук.'

    def _handle_ha(self, args: dict) -> str:
        return self.smarthome.control(
            action      = args.get('action', ''),
            entity_name = args.get('entity_name', ''),
            brightness  = args.get('brightness'),
            color       = args.get('color'),
            temperature = args.get('temperature'),
        )

    async def _end_dialog(self):
        log.info('Ending dialog...')

        # Clear mic consumers FIRST — prevents further send_audio calls
        self.mic.clear_consumers()

        # Play the chime and switch the LED immediately (after clearing any
        # leftover Gemini audio), same as the start side — don't make the
        # user wait through gemini.disconnect()'s WebSocket close or
        # Spotify's volume-restore call (up to 3s) just to see/hear the
        # "dialog ended" cue. (enter_idle() below still does the rest of
        # the IDLE transition — mic consumer, button handler, self.state —
        # once cleanup actually finishes; only the LED color needs to jump
        # ahead of that.)
        self.speaker.clear()
        chimes.dialog_ended()
        leds.idle()

        if self.gemini:
            await self.gemini.disconnect()
            self.gemini = None

        # Restore Spotify volume — only if we actually ducked it. Otherwise
        # this has the exact same hijack risk the duck-check above guards
        # against: set_volume() would transfer playback onto Chochko from
        # whatever device is currently playing, even though we correctly
        # left it alone at duck time.
        if self.spotify.connected and self._spotify_ducked:
            try:
                await asyncio.wait_for(
                    self.loop.run_in_executor(None, self.spotify.set_volume, 100),
                    timeout=3.0
                )
            except Exception:
                pass
            self._spotify_ducked = False

        self.wakeword.reset(cooldown=1.0)
        await asyncio.sleep(1.0)

        log.info('Dialog ended')
        self.enter_idle()

    # ── MAIN ──────────────────────────────────────────────────────────

    async def run(self):
        self.enter_idle()
        log.info('Чочко ready — say the wake word or press the button')

        stop = asyncio.Event()
        self.loop.add_signal_handler(signal.SIGINT,  stop.set)
        self.loop.add_signal_handler(signal.SIGTERM, stop.set)
        await stop.wait()


async def main():
    assistant = VoiceAssistant()
    loop      = asyncio.get_event_loop()
    assistant.setup(loop)
    try:
        await assistant.run()
    finally:
        assistant.teardown()


if __name__ == '__main__':
    asyncio.run(main())

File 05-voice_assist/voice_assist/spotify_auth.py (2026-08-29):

#!/usr/bin/env python3
"""One-time Spotify authorization for the voice assistant (headless / no browser
on the Pi).

Produces ~/.spotify_cache — the exact token cache that spotify.py reads. Run it
once; afterwards SpotifyController.connect() finds the cached token and refreshes
it automatically.

Usage:
    export SPOTIFY_CLIENT_ID='...'
    export SPOTIFY_CLIENT_SECRET='...'
    python3 spotify_auth.py
"""
import os
import sys

import spotipy
from spotipy.oauth2 import SpotifyOAuth

# Must match spotify.py exactly:
SCOPE = (
    'user-read-playback-state '
    'user-modify-playback-state '
    'user-read-currently-playing'
)
REDIRECT_URI = os.environ.get(
    'SPOTIFY_REDIRECT_URI', 'http://127.0.0.1:8888/callback'
)
CACHE_PATH   = os.path.expanduser('~/.spotify_cache')
DEVICE_NAME  = 'Chochko'


def main():
    cid = os.environ.get('SPOTIFY_CLIENT_ID')
    sec = os.environ.get('SPOTIFY_CLIENT_SECRET')
    if not cid or not sec:
        sys.exit('Set SPOTIFY_CLIENT_ID and SPOTIFY_CLIENT_SECRET first.')

    auth = SpotifyOAuth(
        client_id=cid,
        client_secret=sec,
        redirect_uri=REDIRECT_URI,
        scope=SCOPE,
        open_browser=False,
        cache_path=CACHE_PATH,
    )

    # If a valid cache already exists, skip straight to verification.
    token = auth.get_cached_token()
    if not token:
        url = auth.get_authorize_url()
        print('\n1. Open this URL in a browser on ANY machine (phone/laptop):\n')
        print('   ' + url)
        print('\n2. Log in and approve. Your browser will then try to load a')
        print('   http://127.0.0.1:8888/callback?code=... page that FAILS to')
        print('   load — that is expected (nothing is listening on the Pi).')
        print('   Copy the ENTIRE address-bar URL of that failed page.\n')
        redirected = input('3. Paste the full redirected URL here: ').strip()
        code = auth.parse_response_code(redirected)
        auth.get_access_token(code, as_dict=False)
        print(f'\nToken cached to {CACHE_PATH}')
    else:
        print(f'Existing valid token found at {CACHE_PATH}')

    # ── Verify end to end ───────────────────────────────────────────────
    sp = spotipy.Spotify(auth_manager=auth)
    me = sp.me()
    print(f'\nAuthorized as: {me.get("display_name")} '
          f'({me.get("product")})')           # should say "premium"

    devices = sp.devices().get('devices', [])
    names = [d['name'] for d in devices]
    print(f'Visible Spotify devices: {names or "(none)"}')

    if any(DEVICE_NAME.lower() in n.lower() for n in names):
        print(f'\n✓ "{DEVICE_NAME}" is visible — voice assistant can target it.')
    else:
        print(f'\n✗ "{DEVICE_NAME}" not visible yet. Make sure raspotify is '
              f'running (systemctl status raspotify) and that it is logged in to '
              f'the SAME account you just authorized. The device often only '
              f'appears after it has played once from the phone app.')


if __name__ == '__main__':
    main()
